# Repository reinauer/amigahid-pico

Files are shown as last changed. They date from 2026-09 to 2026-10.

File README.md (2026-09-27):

# amigahid-pico

please note: the interesting stuff goes into the [development](https://github.com/borb/amigahid-pico/tree/development) branch, so if main seems slow, check it out.

## introduction

amigahid-pico uses the rp2040 microcontroller (e.g. the raspberry pi pico) in a carrier board to attach usb input devices to a standard amiga without the need for a usb stack on the amiga itself.

it currently supports keyboards and mice and provides connection via the internal keyboard connector, the rj11/din socket on big-box amigas, and via the controller ports.

**this project is very much a work in progress.**

## **important note**

* current kicad files are for r5 pcb. on the `features` branch, select `BOARD_HIDPICO_REV5` to enable both controller ports: port 1 defaults to mouse and port 2 to USB joystick. REV4 firmware supports the same keyboard and first port, but leaves the second port unused. see [USB joystick mode](./doc/joystick.md).

* **always read the [errata](./doc/errata.md) section for the current pcb layout before deciding whether or not to build.**

rev 5 pcb

## documentation

* [installation](./doc/installation.md)
* [hardware](./doc/hardware.md)
* [errors in revisions (errata)](./doc/errata.md)

## history

this project is a rewrite of the [amigahid](https://github.com/borb/amigahid) project to the rp2040 microcontroller.

originally, after the retirement of the arduino adk board and shortening availability of the max3421e "usb host shield" for arduino boards, the need for a cheap, easy and continually available replacement was sought.

at first, the uhs mini via a level shifter seemed ideal, but significant issues were found convincing it to work with a variety of arduino boards.

the rp2040 made sense as a target because it is widely available, has sufficient physical connections and is powerful enough to meet multiple needs.

## what is the latency of this?

i have not measured the latency, but the keyboard signals are sent out the moment they are received on the usb bus. the potential latency is likely fractionally longer than the amiga mcu but bear in mind the rp2040 is significantly faster than the standard amiga keyboard controller.

## roadmap

please see the issues tab on the [github repository](https://github.com/borb/amigahid-pico) for the current list of planned features. the tl;dr is:

normal:
* i<sup>2</sup>c display for config/status
* controller emulation
    * keyboard-based controller emulation (use udlr for directions?)
* flash memory-based configuration
* possible amiga-side control panel (using bidirectional controller port signals)
* rotary control simulation (for controlling gotek drives)

crazy talk:
* non-amiga support
* non-hidbp support
* analogue/paddle emulation
* fix some tinyusb issues (hotplug, timing-related instability)

## license

on the fence at the moment, but the current license choice is Eclipse Public License 2.0 (EPL-2.0).

## third party licenses

* µgui: this code contains 'µgui' by achim döbler; the license for this can be read at in the [display readme](./src/display/README.md)

## whuh... who?

nine <[nine@aphlor.org](mailto:nine@aphlor.org)>

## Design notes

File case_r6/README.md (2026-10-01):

# AmigaHID Pico r6 case

YAPP enclosure for `../kicad_r6/amigahid-pico.kicad_pcb`. Outside dimensions are
**75.6 × 76.0 × 26.5 mm**. The base and lid are separate snap-fit parts. The lid uses **blind internal clip
recesses**, leaving 0.8 mm of continuous exterior wall. Matching base clips are
shortened with 0.15 mm clearance; print the updated base and lid together.

Run the build command below to generate the STL files and previews locally.
Generated `build/` files are intentionally excluded from Git.

## Print files

- [Base STL](build/base.stl), floor down.
- [Lid STL](build/lid.stl), exterior top face down; already oriented for printing.
- [Both parts](build/print.stl), separated on one build plate.
- [Editable OpenSCAD design](amigahid-pico-case.scad).
- [PCB and connector fit preview](build/fit.png), with simplified component envelopes.

PETG and a 0.2 mm layer height are reasonable starting settings, carried over from
the original case. Tune `ridgeSlack` and the port clearance after a first print.
This is a geometrically checked prototype, **not a physically test-fitted enclosure**.

## r6 changes

The original sibling repository was copied into this directory. Its original SCAD, README, assets and unused STEP helpers remain local-only
and are excluded from Git; the source license is retained. The r6 SCAD uses the actual
[YAPP_Box generator](https://github.com/mrWheel/YAPP_Box), vendored at commit
`f9400c419ef1dea7dc0b3607876989b4f3faa2b7` with its MIT license. Original case source:
`../amigahid-pico-case`, commit `84d0b1838114eac426ddd242eb8ad227578d349e`.

Coordinates are extracted from the current PCB, not copied from the old case.
Case X = KiCad X; case Y = 68 − KiCad Y, plus the wall and padding offsets.
The PCB origin lies at case (2.8, 5.2) mm, with the PCB top at Z=7.6 mm.

| Feature | Position and opening |
|---|---|
| J5/J6 DE9 | Two 32.0 × 13.7 mm openings on the +Y wall, at PCB X=17.54 and 51.54 mm; includes flange and screw access. |
| J7 A4000 mini-DIN | Ø15 mm opening on the +X wall, at PCB Y=20 mm, centre 6.55 mm above PCB. |
| J4 USB-A | 15.7 × 8.29 mm opening on the +X wall, at PCB Y=50.5 mm, centre 3.545 mm above PCB. |
| OLED | 32.22 × 17.5 mm lid window centred at PCB (51.0, 48.2) mm; matches the supplied 1.3-inch SH1106 drawing. |
| H5/H6 | Ø4.4 mm printed supports, 3 mm above the floor, at PCB (2.7,63) and (53.3,22.5) mm. |
| J9 external 5V | Optional 9 × 7 mm pigtail opening on the −Y wall, aligned with J9. Disabled by default. |
| J1 A500 cable | Optional 6 × 7 mm opening on the −X wall. Disabled by default for mini-DIN keyboard use. |

Connector openings use supplier mechanical drawings, including the offset between
DE9 footprint origins and their actual shell centres. Nominal shell dimensions:
DE9 30.8 mm wide × 12.5 mm high; JST USB-A 14.5 × 7.09 mm; DIN-603 14.2 mm
wide × 13.1 mm high. Supplier drawing URLs are recorded in `../kicad_r6/SOURCING.csv`.
The DIN opening allows plug mouldings up to about 14.4 mm diameter with clearance;
measure unusually bulky cable boots before printing.

The Pico antenna has the PCB's 14 × 9 mm notch beneath it and an extra 3 mm gap
at that end of the enclosure. There are no support posts in that region. Use a
nonmetallic case and nylon hardware; the base remains a continuous plastic floor.

## Assembly

1. Clear/tap the two 1.7 mm support pilots for M2 threads. Fix the PCB with
   **two M2 × 4 mm nylon screws** through H5/H6. Longer screws can bottom out.
2. Mount the OLED on **four 12 mm M3 nylon spacers** through H1–H4. The case
   supports the main board; it does not duplicate the OLED mounts in the lid.
3. The display stack assumes a 1.2 mm module PCB and 2.6 mm glass height above
   it. This leaves **0.6 mm** beneath the lid. Confirm the assembled stack before
   snapping shut; adjust `oled_standoff`, the stack dimensions and case height
   together if your module differs. The female J3 socket needs sufficient mating
   pin length to bridge the 12 mm spacing; use flying leads if necessary.
4. Set JP1 to the intended power source, connect the display and close the lid.
   Pico programming USB, BOOTSEL, JP1 and debug/experimental headers are accessed
   with the lid removed. No programming extension or push-button is included.

J9 is a PCB header, **not a panel power jack**. Its opening is for a low-profile
wired pigtail with strain relief added during assembly. A tall straight Dupont
plug under the OLED will not fit this stack. The wall is closed by default for Amiga keyboard power. Set
`external_power_opening=true` to enable the auxiliary-power cable opening.
The optional J1 cable opening similarly assumes flexible/low-profile wiring.

## Rebuild and checks

Open `amigahid-pico-case.scad` in OpenSCAD. `view` supports `print`, `base`, `lid`,
`assembled`, `fit` and `collision`. Change `oled`, `external_power_opening` or
`a500_cable_opening` to select apertures.

```sh
# From the repository root; requires KiCad's Python module.
/usr/bin/python3 case_r6/tools/extract_pcb.py
# Requires OpenSCAD on PATH, or OPENSCAD=/path/to/openscad.
python3 case_r6/tools/build.py
```

The generated, local-only `pcb-mechanics.json` records the source PCB hash and measured component positions.
`pcb-mechanics.scad` is a small committed geometry input so OpenSCAD can open
the design without a KiCad Python installation.
Extraction updates placement coordinates; board outline and connector type changes
still need mechanical review. Current cutout dimensions and pin-centre corrections
are for the selected r6 component part numbers.

The exported base and lid were checked for closed edges, positive volume, and
exactly one connected solid each. See `build/mesh-validation.json`. The modelled
PCB, connector, Pico and OLED envelopes have **zero volume of interference** with
the assembled enclosure. A 0.01 mm separation excludes intentional support/PCB
contact from that Boolean test. This checks nominal body clearance; it does not
validate every cable boot, solder joint, screw, printer tolerance or snap force.

The build also exports CSG for both parts. STEP conversion is not included or
validated in this revision.

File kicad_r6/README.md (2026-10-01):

# AmigaHID Pico r6 — prototype hardware

Open `amigahid-pico.kicad_pro` with KiCad 10. This directory was copied from
`../kicad`; the original r5 files and existing firmware edits are untouched.
The schematic and PCB in this directory are the r6 design, not fabrication-proven hardware.

## Implemented

- Pico **W** (RP2040, LCSC C7203003) fitted by default; also supports Pico **2 W**
  (RP2350) on the same footprint. Both modules provide Wi-Fi/Bluetooth. A bare RP2350 + RM2 design is
  deferred; it requires a separate MCU power/flash/clock/RF layout.
- Two **SN74CBTD3861DBQR** 10-channel bus switches replace all 17 BSS138 level
  shifters. Ten isolated 4 × 10 kΩ resistor arrays replace 34 individual
  pull-ups; unused resistor channels and switch channels are intentionally NC.
  These are the **CBTD** parts, powered from 5 V; CBTLV3861 is not a substitute.
- Two PCB-mounted **female DE9** connectors, numbered by actual DE9 pins rather
  than the old IDC/ribbon interleave. They connect to the Amiga's male ports.
- A **6-pin mini-DIN A4000 keyboard link**, for the user's straight-through
  PS/2-to-PS/2 cable and A4000-to-A3000 mini-DIN/DIN adapter. The signalling is
  Amiga keyboard protocol. This is not a PC PS/2 keyboard input.
- A four-pin female OLED socket, **3V3 / GND / SCL / SDA**, matching the supplied
  SH1106 module pin table. GPIO2 is SDA; GPIO3 is SCL.
- Four 3.2 mm carrier holes for M3 nylon standoffs on **30.50 × 28.60 mm** centres.
  The OLED outline is **35.50 × 33.70 mm**, from the supplied mechanical drawing.
- One USB-A host port. Full underside Pico W USB pads replace the old board
  crevice / half-via attachment. GPIO14/15 are exposed at J8 for a future PIO-USB
  experiment; the USB-A port currently uses the native USB controller.
- External 5 V input and a power-source selector, plus a 500 mA hold PTC on the
  USB host branch. An external powered USB hub provides multiple device ports.

Two additional case mounts, H5 at (2.70, 63.00) mm and H6 at (53.30, 22.50) mm,
use **2.2 mm holes for M2 nylon screws/standoffs**. Coordinates are measured from
the top-left board corner. Use hardware no wider than 4.4 mm at the PCB; M3
hardware crowds the Pico. H1–H4 remain the OLED mounts.

The carrier has a **14 × 9 mm antenna notch** from x=10 to 24 mm and y=59 to
68 mm, open to the bottom edge. This removes the carrier substrate beneath the
antenna, following the module footprint’s suggested board edge. Keep case metal
and mounting hardware out of that antenna space.

Board bounding outline: **70 × 68 mm**, two copper layers. The bounding rectangle is about 6.4% greater area
than the original outline's 61.772 × 72.443 mm bounding box. The level-shifting
section is smaller; the direct connectors and OLED mounting determine the
carrier size. Three onboard USB sockets and an onboard hub are not included.

## LCSC sourcing

`SOURCING.csv` records the selected manufacturer part numbers, live LCSC stock
counts, check timestamps, datasheet links, and footprint checks. The schematic
and PCB use only **LCSC Part #**, the field recognized by the Fabrication Toolkit
plugin. `production/bom.csv` uses the same **LCSC Part #** column. LCSC stock does not itself guarantee JLC assembly stock
or eligibility; check those when uploading the BOM.

All 32 electrical components have stocked LCSC selections. **U1 is Pico W,
C7203003**, selected after checking both official pinouts and SMT drawings.
Pico 2 W is an optional separately sourced alternative. Use firmware built for
`pico_w` with the fitted RP2040 module or `pico2_w` with the RP2350 alternative. The OLED, standoffs, cables, and JP1 shunt are separate assembly
accessories; mounting holes are not purchasable components.

- U1: C7203003, Raspberry Pi Pico W. See `review/sourcing/pico-compatibility.txt`
  for the underside-pad and shell-contact verification.
- U2/U3: C44508, TI SN74CBTD3861DBQR (SSOP-24, 0.635 mm pitch). This replaces
  the initially selected PWR/TSSOP package; the electrical pin assignments are
  unchanged. Use the updated PCB, not the previous TSSOP fabrication files.
- J7: C7428703, HOOYA DIN-603. The six signal holes, 13.9 mm shield spacing,
  central 3 × 1 mm shield slot, and signal numbering match the local footprint.
  Numbering was cross-checked against LCSC’s EasyEDA model as well as the drawing.
- J5/J6: C50380980, LCK-205A09FJ2A00B1A. Signal drills are 1.10 mm to meet the
  supplier’s 1.09 mm hole recommendation; 25 mm mounting-hole pitch is retained.
- J4: C7279912, JST UBA-4R-D14-4D(LF)(SN), matching the existing USB signal and
  shield-hole pattern. USB routing is retained.
- Connector 3D bodies are illustrative, not exact supplier mechanical models.

`review/sourcing/stock-snapshot.json` preserves the stock evidence. Stock counts
are a dated snapshot, not a reservation or an ongoing availability guarantee.

Assembly rotation corrections use `FT Rotation Offset` for Fabrication Toolkit:
U1 = 270°, C4 = 180°, J7 = 0°, and J1–J6/J8/J9/JP1 = 90°.
These offsets incorporate the assembly-preview corrections: U1 and C4 turned
180° from the preceding export, and J7 turned 90° clockwise. They affect only
exported placement rotation. Review pin 1, C4 polarity and connector openings
in the JLC preview after re-uploading the CPL.

## Power and assembly

**Default: regulated 5 V into J9, with a 2 mm pitch shunt on JP1 pins 2–3.**
J9 pin 1 is +5 V input; pin 2 is ground. Supply at least the measured Pico +
peripheral load; a current-limited 5 V bench supply is appropriate for bring-up.
The selector keeps the Amiga's keyboard +5 V separate in external-power mode.
Do not bridge both selector positions. Grounds remain common. Power the adapter and Amiga together; automatic I/O
isolation when either supply is off is not implemented and needs bench review.

JP1 pins 1–2 select power from the Amiga keyboard connector. Use that option
only after checking the actual machine's port budget; the complete 500 mA USB
branch must not be assumed available from a keyboard port. The PTC is overload
protection, not a precise 500 mA current regulator or a USB power-distribution
switch. Use a powered hub for multiple USB loads. DE9 pin 7 is deliberately NC
on both ports, so mouse-port supplies are not paralleled with keyboard power.

D1 feeds Pico VSYS through a Schottky diode, preventing the Pico's programming
USB supply from feeding the selected board rail. Disconnect host devices when
connecting a PC to the Pico's native USB connector: the two connectors share
D+/D-. Do not connect two USB hosts to those data lines.

The Pico module must be **surface mounted/reflowed**, including TP2 and TP3;
plugging it into ordinary 40-pin sockets does not connect the USB test pads.
The local Pico footprint retains the wireless antenna keepouts and omits only
two paste-only apertures which conflicted with its RF keepout. No connector,
OLED metalwork, ground fill or trace should extend into the antenna keepout.

The OLED pin row starts 11.28 mm to the right of the upper-left mounting-hole
centre and 1.54 mm below its PCB top edge, following the supplied drawing.
Use a matching four-pin female socket on the carrier. Approximately 11 mm
board-to-board spacing suits an 8.5 mm socket plus a 2.54 mm male-header body;
**dry-fit the actual supplied header and standoffs before assembly**. All four
OLED holes are part of the carrier; the module outline is on Dwgs.User.
Use nylon spacers to avoid shorting OLED tracks. The display sits above the
carrier components; confirm connector insertion clearance in the assembled stack.

## Connector pinouts

| Connector | Pins |
|---|---|
| J1 A500 | 1 KCLK, 2 KDAT, 3 /RESET, 4 Amiga +5 V, 5 NC, 6 GND, 7 NC, 8 NC |
| J2 UART/SWD | 1 GND, 2 GPIO0/TX, 3 GPIO1/RX, 4 SWDIO, 5 GND, 6 SWCLK |
| J3 OLED | 1 3V3, 2 GND, 3 SCL/GPIO3, 4 SDA/GPIO2 |
| J5/J6 DE9 | 1 Up, 2 Down, 3 Left, 4 Right, 5 button 3, 6 Fire, 7 NC, 8 GND, 9 button 2 |
| J7 A4000 | 1 KDAT, 2 NC, 3 GND, 4 Amiga +5 V, 5 KCLK, 6 NC; shell GND |
| J8 experiment | 1 GND, 2 GPIO14, 3 GPIO15, 4 3V3; no USB firmware or 5 V power at this header |
| J9 external supply | 1 regulated +5 V, 2 GND |
| JP1 2 mm selector | 1 Amiga +5 V, 2 board +5 V, 3 external +5 V; fit one shunt, default 2–3 |

Check the PS/2 cable for **pin-for-pin continuity**, especially 1, 3, 4 and 5.
The A3000 adapter must map A4000 mini-DIN data/clock/ground/supply to the matching
A3000 DIN signals. Do not infer numbering from the mating face or wire colours.
The mini-DIN does not carry A500 /RESET; J1 retains that signal.

## Firmware compatibility and remaining validation

Amiga GPIO assignments retain `BOARD_HIDPICO_REV5`, including the corrected
port-2 GPIO26/GPIO27 mapping. Firmware must drive the Amiga outputs LOW or
release them; the existing keyboard and controller drivers already do that.
The bus switches do not actively generate a 5 V HIGH; the 5 V pull-ups do.

A local Pico 2 W + Bluetooth build was attempted and failed at `src/settings.c:41`:
`Settings overlap Bluetooth pairing storage`. The installed picotool is also
2.2.0-a4 while this SDK requires 2.3.0; the compile check used
`PICO_NO_PICOTOOL=ON`, so it could not produce a UF2 even if compilation passed.
Resolve the flash partition configuration before treating RP2350 firmware as
ready. Logs are in `review/firmware-*.log`.

Pico 2 W requires a `pico2_w`/RP2350 firmware build with Bluetooth enabled;
Pico W requires `pico_w`/RP2040. A wireless footprint alone does not enable
Bluetooth in a firmware image. Existing firmware source is not changed here.

**The current display driver is SSD1306, not SH1106.** Despite the seller's
compatibility wording, SH1106 needs page-addressed writes, its DC/DC commands,
a typical two-column RAM offset and an I2C speed no higher than its specified
400 kHz. The current 1 MHz SSD1306 horizontal-addressing driver must be adapted
before the requested display can work. This hardware provides the correct
supply, signals and mounting, but does not claim SH1106 software support.

Before promoting this prototype to a manufacturing release:

1. Dry-fit the selected connectors, OLED/socket/spacers and cables. Supplier
   footprint checks and the exact selected parts are recorded in `SOURCING.csv`.
2. Check continuity, diode polarity, power selector isolation and all connector
   pinouts without an Amiga attached. Verify 5 V supply and 3.3 V rail sequencing.
3. Scope LOW/HIGH levels on both sides of both CBTD3861s under actual Amiga
   pull-ups and cable loads, including reset, simultaneous transitions, startup
   and shutdown. TI specifies the part's operating supply as 4.5–5.5 V.
4. Check the Pico pins for overshoot/back-powering in every supply state. The
   CBTD3861's transfer curve is not an absolute overvoltage clamp guarantee.
5. Test USB enumeration/hotplug with a keyboard, mouse and joystick through a
   powered hub. Check inrush, PTC heating, supply drop and USB waveform quality.
   The manually routed pair is matched to below 0.3 mm; this alone is not USB
   compliance or a verified 90-ohm impedance calculation for a chosen fab stackup.
6. Verify Bluetooth operation and RF range with the display and enclosure fitted.
7. Implement/test SH1106 firmware and verify the image reaches all display edges.

No remote release/tag is published and no fabrication order is placed.

## Files and reproducibility

- `amigahid-pico.kicad_pro`, `.kicad_sch`, `.kicad_pcb`: editable r6 project.
- `SOURCING.csv`: reviewed electrical component list with `LCSC Part #` fields.
  Run `python3 scripts/sync_sourcing.py` to generate `BOM.csv`; add OLED, a 2 mm shunt,
  four M3 nylon spacers and mating power/display connectors to the assembly order.
- `review/oled-*.png` and `review/sourcing/`: supplied mechanical drawings and
  sourcing evidence. Downloadable supplier PDFs are linked in `SOURCING.csv`.
  Exported schematics, board previews, validation reports, Gerbers and production
  files are generated locally and excluded from Git.
- `scripts/sync_sourcing.py`: reapplies reviewed `SOURCING.csv` metadata to the
  schematic, PCB and BOMs without changing the circuit or layout. It does not
  refresh live stock automatically.
- `scripts/validate_r6.py`: repeat the connectivity, mechanics, ERC and DRC checks
  using `/usr/bin/python3 scripts/validate_r6.py` from this directory.
- Local footprint/symbol libraries are project-relative. Only the four r6
  footprints and the required mini-DIN model are tracked. KiCad 10 supplies the
  remaining standard footprints and models. r5 references, caches and one-off
  placement/routing generators are excluded from Git.

## Sources

- [TI SN74CBTD3861 product page](https://www.ti.com/product/SN74CBTD3861)
  and [datasheet](https://www.ti.com/lit/ds/symlink/sn74cbtd3861.pdf).
- [Raspberry Pi Pico 2 W datasheet](https://datasheets.raspberrypi.com/picow/pico-2-w-datasheet.pdf).
- [Raspberry Pi RM2 documentation](https://www.raspberrypi.com/documentation/microcontrollers/radio-modules.html).
- [Commodore A4000 schematic, CN175](https://www.amigawiki.org/dnl/schematics/A4000_Rb.pdf).
- [Sino Wealth SH1106 datasheet](https://www.crystalfontz.com/controllers/SinoWealth/SH1106/468/).
- OLED dimensional drawing and pin table supplied by the user in this session;
  saved under `review/` with the original dimensions visible.

Original project author: nine <nine@aphlor.org>. See the repository README for
the project's Eclipse Public License 2.0 licensing statement.

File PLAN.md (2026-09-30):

# Implementation status: features branch (2026-09-29)

Based on `bluetooth` at `b437643`. The existing Bluetooth PR is unchanged.

Implemented in the first runtime-configuration milestone:

- Versioned settings with CRC validation, defaults, and two alternating flash
  records. Settings storage is separate from Bluetooth pairing data.
- OLED settings menu entered by holding F12 for one second; arrow navigation,
  save, cancel, and factory defaults. Input is captured while the menu is open.
- Menu key/entry policy, Right GUI behavior, wheel enable/direction,
  quadrature timing presets, display diagnostics/off, and optional watchdog.
- Fixed boot recovery: hold F12+Esc for two seconds during the first ten seconds
  of input servicing. Defaults are applied in RAM; save explicitly to keep them.
- The watchdog feeds only after the main-loop services return; it is off by
  default. USB-only builds also initialize core1's flash lockout support.

Hardware check on Pico W/REV5 (initially using the REV4 firmware): the menu works,
and a saved 5-second watchdog setting survives power loss. Recovery and an actual watchdog-triggered restart
still need hardware validation.

Usage and validation notes: [doc/runtime-configuration.md](doc/runtime-configuration.md).

Implemented in the digital-joystick milestone:

- USB HID gamepad/joystick hat switches, discrete D-pad inputs and absolute X/Y
  fields, with Button 1 as fire. Reports are decoded from their descriptors,
  including report IDs. X/Y uses a central deadzone and digital output.
- A dedicated REV5 build defaults to mouse on controller port 1 and USB joystick
  on port 2 simultaneously. Port 1 can still select joystick; port 2 has an Off
  option. REV2/REV4 retain port 1 only. Core1 owns output pins; menu entry, mode
  changes and disconnects release controls. Opposing directions cancel.
- Settings schema 3 migrates schema 1 and 2, preserving existing settings and
  enabling the new port 2 option by default on REV5. A saved port 1 joystick
  selection is retained; change it to Mouse for the two-port arrangement.

Usage and supported formats: [doc/joystick.md](doc/joystick.md).

Competition Pro Extra (`0079:181c`) input checked on Linux: its digital stick uses
X/Y values 0/128/255, with the advertised hat unused. Native decoding checks pass
using the actual descriptor and captured axis values. All four buttons produced
events. Initial hardware testing detected the controller, but Amiga Test Kit showed no
activity on either port, including port 1 through the working mouse cable.
HID diagnostics now expose USB report count/length, decoding, routed controls
and waiting for neutral. On direct USB connection, the stick showed zero received
reports and an advertised 49-byte layout instead of Linux's 9-byte layout.
A PS3 startup trial now matches `054c:0268` plus the 49-byte report ID 1 layout
before enabling input, and maps PS3 face buttons to fire. The user confirmed that
`0.3.0-dev-12-g4da9d14` works on REV5 by playing Great Giana Sisters. The controller's
USB identity was not read back directly; the successful initialization supports
the PS3-mode explanation. Detailed unplug/menu/diagonal checks remain outstanding.

Implemented in the Bluetooth LE gamepad milestone:

- Active LE scanning includes scan responses. Devices without keyboard/mouse boot
  reports use BTstack's HIDS host to discover report maps and subscribe to input.
- Standard HID gamepad reports feed the existing digital joystick path. The Stadia
  Bluetooth descriptor has native coverage for D-pad, left stick and A/fire.
- The Bluetooth queue preserves the latest gamepad state on overflow and releases
  controls on disconnect. OLED status identifies an accepted LE gamepad, with
  report/decoding/output diagnostics when no USB joystick is connected.
- Controller menus now say Joystick because the same mode accepts USB and LE
  input. Existing saved settings and the REV5 mouse/joystick defaults are preserved.
- Stadia is the first hardware target. Keyboard-as-joystick is deferred at the user's
  request; Bluetooth gamepads take priority.

Hardware check on Pico W/REV5 with `0.3.0-dev-13-gde9ae63`: Stadia connected,
the OLED reached `bt c0 le:ready j1`, and D-pad directions and A/fire worked on
Amiga port 2 in Amiga Test Kit. Left-stick thresholds, disconnect release,
reconnection and extended play still need hardware validation. The USB-only
device counters remain unchanged; Bluetooth status is shown on the second line.

Implemented in the PS4 Bluetooth trial:

- Classic inquiry automatically finds joystick/gamepad devices and opens HID
  connections. Discovery pauses once a Classic gamepad is accepted and resumes
  on disconnect; incoming keyboard/mouse connections remain supported.
- Standard Classic gamepads use the existing descriptor decoder. DualShock 4
  Bluetooth uses a descriptor-matched decoder for basic and extended reports:
  D-pad/left stick supply directions and Cross supplies fire.
- Extended reports are requested for touchpad input. A finger drives relative
  mouse movement on port 1; pressing the pad supplies left-click. Contact tracking
  prevents jumps on lift/re-touch. Extended reports are length/CRC checked.
- Bluetooth diagnostics include Classic gamepads. No settings schema changes.
- Temporary native checks cover discovery, pairing failures, incoming reconnect,
  published descriptors, joystick/touchpad reports and disconnect release.
  The user confirmed the initial trial works on REV5, including touchpad
  left-click. Reconnect and long-running stability still need hardware checks.

Implemented in the additional-buttons trial:

- Joystick buttons 1/2/3 drive Amiga pins 6/9/5 on each enabled joystick port.
  PS4 uses Cross/Circle/Square, Stadia uses A/B/X. Generic HID uses Buttons
  1/2/3, falling back to Button 4 for the third fire if Button 3 is absent.
  The Competition Pro PS3-mode four-buttons-as-fire mapping is preserved.
- PS4 L1/touchpad press supply left-click, R1 right-click, and either L2 or R2
  supplies middle-click on the mouse port. USB/Bluetooth mouse buttons are
  combined so one device cannot release a button held on another.
- Temporary checks cover button combinations, source aggregation, menu capture,
  disconnect release, and all seven digital output lines on both REV5 ports.
  No settings schema changes or new checked-in tests.

Hardware check on Pico W/REV5 with `features-ps4-stadia-buttons-20260928`
(`0.3.0-dev-14-g7489e0d*`): the user confirmed that PS4 and Stadia joystick
buttons 1/2/3 and the PS4 mouse button mappings all work as expected.
Reconnect and long-running stability still need hardware validation.

Implemented in the configuration and CD32 milestone (hardware test pending):

- Bluetooth radio On/Off, automatic or bonded-only pairing policy, a timed pairing
  action and confirmed removal of Classic/LE bonds. Stored LE identities support
  private-address resolution. Radio shutdown discards stale input and releases controls.
- Gamepad D-pad/stick selection, three deadzones, seven configurable button sources,
  and PS4 touchpad/shoulder mouse controls. Controller-specific defaults are retained.
- Keyboard Help/Delete choices, ISO-key selection, letter-layout presets and eight
  learned-source custom remaps. Translated keys are aggregated across devices so
  aliases and shared modifiers stay held until every source releases them.
- CD32 pad mode on supported ports: PIO provides the seven-button shift register,
  identification bits and fire/clock handover. REV5 can retain mouse on port 1 and
  CD32 on port 2. Explicit CD32 mode preserves ordinary joystick as the default.
- Settings schema 7 reads schemas 1–6 and preserves saved choices. Live settings
  are published atomically to Bluetooth callbacks. No CAD changes or new checked-in tests.
- Temporary checks pass settings migration/interrupted writes, menu actions, key
  aliases and reset chord order, seven-button decoding, Bluetooth power/pairing/
  forget transitions, parser mutation cases, GPIO routing and assembled CD32 PIO
  behavior. CD32 recognition/electrical timing and the new menu settings need the
  user's combined hardware test; software simulation is not hardware validation.

Still to implement or validate:

- Test the four new feature groups on Pico W/REV5, including saved settings,
  controller disconnect/reconnect, held-control release and extended use.
- Validate boot recovery and an actual watchdog-triggered restart.
- Measure input latency and validate faster mouse timing presets on hardware.
- Earlier HID rearming and GPIO timing instrumentation.
- Keyboard PIO; consider mouse PIO only after measurement.
- Keyboard-as-joystick remains deferred at the user's request.
- Additional controller formats and optional automatic port mode selection.
- Full national keyboard layouts beyond the letter presets/custom remaps, and
  arbitrary remapping beyond the eight custom slots.
- The optional Amiga preference tool.

The sections below retain the design and acceptance criteria for these phases.

# PIO Offload Plan

## Goal

Reduce end-to-end input latency without regressing keyboard or mouse
reliability on the Amiga.

## Current State

- USB host processing runs on `core0`.
- Keyboard state updates still happen on `core0`, but the blocking
  Amiga wire transmission is now queued out of the HID callback path.
- The current keyboard sender still bit-bangs the Amiga serial protocol,
  but that work is now serviced from the normal event loop instead of
  stalling USB report handling directly.
- Mouse quadrature output already runs on `core1`.
- The current mouse path uses a 64-bit deadline with a default 300 us step
  interval. The features branch makes that interval configurable; faster
  presets still need hardware validation.

## Priority

1. Tune or redesign mouse pacing.
2. Measure the result.
3. Shorten the HID hot path further if needed.
4. Only implement mouse PIO if measurements still justify it.

## Phase 1: Measure Baseline

- Add simple timing instrumentation for:
  - USB report received
  - keyboard send start and end
  - first mouse quadrature edge after a report
- Compare:
  - direct USB mouse and keyboard
  - the same devices through the KVM
- Record:
  - typical latency
  - worst-case latency
  - burst behavior

## Phase 2: Decouple Keyboard Sending

Completed.

- Stop sending Amiga keyboard codes directly from the HID callback path.
- Add a small queue for translated Amiga key events.
- Keep key translation, modifier tracking and caps lock handling on
  `core0`.
- Move the actual wire-level transmission out of the synchronous USB
  path.

## Phase 3: Implement Keyboard PIO

- Replace the current blocking keyboard bit-bang transmitter with a
  PIO-backed sender.
- Feed pre-encoded key events into a PIO state machine from software.
- Preserve current behavior for:
  - key up and key down encoding
  - caps lock special handling
  - Ctrl-Amiga-Amiga reset behavior
- Keep a software fallback until the PIO path is validated on hardware.

## Phase 4: Reevaluate Mouse Latency

- Re-test after the keyboard work lands.
- Measure whether the remaining mouse lag is dominated by:
  - KVM polling or buffering
  - the `motion_divider`
  - the fixed `300 us` quadrature pacing
- If needed, make the quadrature step delay configurable and test lower
  values before attempting a larger rewrite.

## Phase 5: Mouse PIO Only If Needed

- Consider mouse PIO only if measurements show that the current
  `core1` quadrature loop is still a significant source of latency or
  jitter.
- A mouse PIO implementation should focus on:
  - precise quadrature timing
  - higher sustained output rate
  - lower burst drain time
- Do not treat mouse PIO as the first optimization target, since the
  current mouse path already avoids blocking USB handling on `core0`.

## Acceptance Criteria

- Keyboard transmission no longer blocks USB event handling for several
  milliseconds per keycode.
- No regressions in key mapping, caps lock behavior or reset chord
  handling.
- Mouse movement remains correct on both axes with no button regressions.
- Measured latency improves in a way that is noticeable on hardware, not
  just in code structure.

## Status Against Earlier Latency Findings

Already addressed in the current tree:

- The old cross-core mouse handoff race has been replaced with a queue.
- Core1 now re-merges newly queued motion between quadrature steps.
- Per-report mouse debug is disabled by default and only enabled when
  `DEBUG_MOUSE` is set.
- Blocking Amiga keyboard transmission has been moved off the USB HID
  callback path into a queue serviced from `amiga_service()`.

Still open:

- Hardware validation of the configurable quadrature timing presets
- HID callback still rearms after handling the report
- No built-in latency instrumentation

## Remaining Work With Estimated Latency Impact

### 1. Make Quadrature Step Timing Configurable

- Implemented on features: select a 300, 200, 150, or 100 us step interval.
  The 300 us default is unchanged; faster presets need hardware testing.
- Test lower values such as `200 us`, `150 us` and `100 us`.
- Choose the lowest value that still tracks reliably on real hardware.

Estimated latency reduction:

- tiny movements: roughly `0-1 ms`
- medium bursts: roughly `3-8 ms`
- `50`-step bursts: roughly `7.5-10 ms`
- very large bursts: up to roughly `20 ms`

This is the highest-value remaining item for pure mouse feel.

### 2. Rearm HID Reports Earlier In The Hot Path

- Copy the essential report data quickly.
- Re-request the next HID report before doing lower-priority work where
  practical.

Estimated latency reduction:

- typical cases: roughly `0-0.2 ms`
- worst-case jitter under load: roughly `0.5-1 ms`

This is now a cleanup improvement rather than the main latency win.

### 3. Add GPIO Timing Instrumentation

- Toggle one GPIO on USB report receipt.
- Toggle another on first emitted quadrature edge.
- Compare direct USB devices against the same devices through the KVM.

Estimated latency reduction:

- direct reduction: `0 ms`

This does not improve latency by itself, but it is the fastest way to
separate KVM delay from firmware delay and validate whether the
remaining work is worth doing.

### 4. Implement Keyboard PIO As A Follow-Up

- Replace the queued bit-bang sender with a PIO-backed transmit path.
- Keep the queue-based architecture, but hand the actual waveform
  generation to a state machine.

Estimated latency reduction:

- USB callback blocking: roughly `0 ms` additional reduction, since the
  main callback decoupling is already done
- keyboard queue drain time under heavy typing: potentially `1-5 ms`
- jitter during mixed input under sustained key bursts: modest but real

This is still worth doing, but it is no longer the first latency item to
attack.

# Joystick Emulation Plan

## Goal

Add joystick and joypad emulation on top of the existing HID input
paths, starting with the simplest and most compatible target.

## Recommended Order

1. HID joystick and gamepad to Atari-style digital joystick
2. Keyboard-to-joystick as an explicit special mode
3. CD32 pad emulation

## Why This Order

- Plain digital joystick is the simplest controller-port target and
  reuses the same physical Amiga port lines already driven for mouse
  emulation.
- Keyboard-to-joystick is useful, but it should be an explicit mode so
  normal typing is not affected.
- CD32 pad support is more complex because the extra buttons are not
  just plain digital joystick inputs and need separate handling.

## Phase 1: HID Joystick to Digital Joystick

USB, LE and Classic HID hat/D-pad, absolute X/Y and multi-button support is
implemented on `features`. Competition Pro, Stadia and PS4 input work on REV5;
complete lifecycle testing and validation of the new configurable thresholds remain outstanding.
See [doc/joystick.md](doc/joystick.md).

- Add a controller backend that drives one Amiga controller port as:
  - up
  - down
  - left
  - right
  - fire
- Parse USB HID joystick and gamepad reports into that state.
- Support D-pad inputs first.
- Add analog stick support after that with deadzones and axis-to-digital
  thresholding.
- Keep the first implementation to one emulated joystick port unless
  the board pin mapping is expanded.

## Phase 2: Keyboard as Joystick Mode

- Add a dedicated mode that maps selected keys to joystick directions
  and fire buttons.
- Start with a sensible default mapping such as:
  - WASD for directions
  - space and ctrl for fire
- Make the feature opt-in so those keys still work normally in standard
  keyboard mode.
- Implement it as a virtual controller source, not as special cases in
  the normal keyboard path.

## Phase 3: CD32 Pad Emulation

Implemented with PIO on `features`; first hardware validation is pending.

- Add a separate backend for CD32-compatible controller output.
- Reuse the basic digital directions from the earlier joystick backend.
- Implement the extra CD32 button handling after the plain joystick path
  is stable.
- Keep this work isolated from the first joystick milestone so the
  simpler one-button case can ship earlier.

## Design Notes

- Reuse the shared input bridge pattern where it helps, so USB and
  Bluetooth controllers can feed the same Amiga-side output path.
- Keep joystick output independent from mouse output, even though they
  share the same Amiga controller connector pins.
- Provide a simple way to select the active emulation mode for a port:
  - mouse
  - joystick
  - keyboard as joystick
  - later, CD32 pad

## Acceptance Criteria

- A standard USB or Bluetooth gamepad can control Amiga software that
  expects a plain digital joystick.
- Keyboard-as-joystick mode works without leaking those keys into normal
  keyboard input when the mode is enabled.
- The initial joystick implementation is stable on hardware and does not
  regress existing mouse emulation.
- CD32 support remains a separate follow-up until the basic joystick
  path is proven.

# Runtime Configuration Plan

## Goal

Move user-facing configuration out of build-time defines where practical
so hardware can be assembled, fitted and adjusted without rebuilding
firmware for small behavioral changes.

## Motivation

- Some choices are annoying to validate only at build time, such as key
  remaps and mode selection.
- A misconfigured modifier or special key can block important machine
  functions such as the Amiga reset chord.
- The board already has an OLED on supported revisions, which makes a
  simple local configuration UI realistic.
- Settings should persist across power cycles and allow recovery to
  defaults.

## Scope

- Keep hardware-specific pin mapping as a build-time concern unless a
  safe runtime board-detection mechanism is added later.
- Move behavioral settings to runtime where possible, such as:
  - HID to Amiga key remaps
  - menu key versus right GUI behavior
  - mouse wheel mode and direction
  - mouse quadrature timing preset
  - port mode selection
  - joystick mode options
  - debug display preferences
  - Bluetooth behavior that does not affect low-level bring-up
- Keep hardware-specific and low-level electrical choices as build-time
  settings:
  - board type
  - GPIO pin mapping
  - PIO allocation details
  - port electrical assumptions

## Phase 1: Define Settings Model

- Add a single settings structure with:
  - version
  - checksum or CRC
  - defaults marker
  - behavioral options only
- Define factory defaults in one place.
- Keep the initial schema small and focused on the highest-value v1
  settings:
  - menu entry key, defaulting to F12
  - menu entry behavior, such as long-press or boot-only
  - right GUI behavior:
    - pass through as Right-Amiga
    - use as menu key
    - disable
  - mouse wheel mode:
    - off
    - TankMouse/Cocolino
  - mouse wheel direction:
    - normal
    - vertical reverse
  - mouse quadrature timing preset
  - debug display mode:
    - normal status
    - HID debug
    - mouse debug
    - off
  - watchdog enable and timeout preset
- Defer broader settings until the core storage and menu path are
  proven:
  - full custom key remapping
  - keyboard layout presets
  - joystick and gamepad mapping
  - Bluetooth pairing policy
  - CD32 pad mode

## Phase 2: Flash Persistence

- Reserve a flash region for configuration storage.
- Add load, validate and save helpers.
- On boot:
  - load settings from flash
  - validate version and checksum
  - fall back to defaults if invalid
- Add a reset-to-defaults path that can be triggered even if saved
  settings are broken.

## Phase 3: Runtime Menu

- Add a display-backed configuration menu for boards with `HAS_SCREEN`.
- Keep the first UI simple and robust:
  - current value
  - next and previous item
  - save
  - reset to defaults
- Avoid requiring a host computer or serial console for normal setup.
- If no display is present, continue to boot with saved settings and
  defer UI work for headless configuration until later.

## Phase 4: Input and Navigation

- Define how to enter the menu safely at boot or runtime.
- Use a key that exists on typical PC keyboards but is not forwarded as
  a normal Amiga key; F12 is the preferred default.
- Support long-press entry at runtime to avoid accidental activation.
- Support a boot-time entry path and a reset-to-defaults gesture so a
  broken saved configuration can be recovered.
- Choose a navigation method that does not require special hardware,
  such as:
  - keyboard keys
  - a connected mouse or controller
  - a held boot gesture
- Ensure the menu can always be exited without corrupting saved state.

## Phase 5: First Runtime-Configurable Features

- Start with settings that solve real deployment pain:
  - menu entry key and entry behavior
  - right-Amiga mapping choice
  - mouse wheel mode and vertical direction
  - mouse quadrature timing preset
  - optional debug screen toggles
  - watchdog enable and timeout choice
- Keep each setting independent and easy to reset.

## Phase 5a: Follow-Up Runtime-Configurable Features

Port/CD32 selection, gamepad settings, Help/Delete choices, letter presets, custom
remaps and Bluetooth controls are implemented. Automatic port detection and
keyboard-as-joystick remain future work. The original design follows.

- Add these after the settings model, flash storage and menu UI are
  stable:
  - controller port mode selection:
    - mouse
    - digital joystick
    - auto, if detection is reliable enough
  - keyboard-as-joystick enable and keymap preset
  - gamepad mapping:
    - D-pad versus analog stick
    - fire button mapping
    - analog thresholds and deadzones
  - Help/Delete mapping choices for different PC keyboard layouts
  - keyboard layout preset
  - Bluetooth enable, pairing mode and forget-paired-devices action
  - CD32 pad mode, once CD32 output is implemented
- Avoid starting with a full arbitrary key remapper; it is useful, but
  it will make the first settings schema and UI much larger.

## Phase 6: Migration and Safety

- Add schema versioning so future firmware can migrate old settings.
- Protect against partial writes and invalid flash contents.
- Make the default path conservative so a bad config does not leave the
  device unusable.
- Document a physical or boot-time recovery path for resetting config.

## Phase 7: Watchdog Support

- Add RP2040 watchdog support around the normal main event loop.
- Feed the watchdog only when the system is making forward progress in
  the expected loop.
- Choose a timeout that tolerates normal long operations but still
  recovers from real hangs.
- Record the last reboot reason where practical so watchdog resets are
  distinguishable from power-on resets.
- Make watchdog support configurable at runtime and default it to the
  behavior that proves least surprising in practice.
- Allow the watchdog to be disabled from saved settings because forced
  reboot behavior may be irritating during development or debugging.

## Watchdog Design Notes

- Do not feed the watchdog from many unrelated places, or it will stop
  detecting the actual main-loop stalls we care about.
- Keep the watchdog decision in the runtime settings model rather than a
  separate ad-hoc switch.
- Ensure there is still a recovery path if a saved watchdog setting is
  undesirable, such as booting into the menu or resetting config to
  defaults.

## Acceptance Criteria

- A user can change common behavioral settings without rebuilding the
  firmware.
- Settings persist across power cycles.
- Invalid or missing settings cleanly fall back to defaults.
- A broken configuration can be reset without external tools.
- The runtime menu does not interfere with normal input handling when it
  is not active.
- Watchdog behavior can be enabled or disabled without rebuilding the
  firmware.

## Experimental Follow-Up: Amiga Preference Panel

- Consider a native Amiga-side preference tool as a later extension of
  the runtime configuration work.
- This would use the controller-port button lines as a low-speed
  bidirectional signaling path only while an explicit configuration
  session is active.
- Do not treat this as the primary configuration path. The OLED menu and
  local runtime settings remain the first-class solution.

### Preconditions

- A reliable local runtime configuration system must exist first.
- The communication mode must not interfere with normal mouse, joystick
  or future CD32 behavior.
- There must be a clear way to enter and leave communication mode.

### Protocol Requirements

- Add an attention or wake-up signal that is unlikely to be triggered by
  normal input activity.
- Use a small half-duplex protocol with:
  - framing
  - versioning
  - checksum or CRC
  - timeout and retry behavior
- Abort cleanly back to normal port behavior if negotiation fails.

### Safety Requirements

- Keep the feature disabled unless explicitly invoked.
- Ensure failed communication cannot leave the controller port stuck in a
  non-input mode.
- Preserve a fully local recovery path through the OLED menu or reset to
  defaults even if the Amiga-side tool is unavailable.

### Scope

- Read current settings
- Change selected runtime settings
- Save settings to flash
- Reset settings to defaults

### Non-Goals for the First Version

- Replacing the OLED menu
- Streaming normal input events over the config channel
- Combining config traffic with normal mouse or joystick emulation at
  the same time

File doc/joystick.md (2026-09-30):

# Joystick mode

The `features` firmware supports a three-button digital joystick and CD32 pad emulation. On REV5 boards,
port 1 defaults to mouse and port 2 to joystick, working simultaneously. Use a
`BOARD_HIDPICO_REV5` build for this arrangement. Keyboard input continues normally,
including access to the settings menu.

## Setup

1. Connect the board's first controller cable to Amiga port 1 and its second cable
   to Amiga port 2. The actual Amiga sockets determine which port software sees.
2. Connect a supported USB HID gamepad or joystick. The OLED's USB `j` count
   increases when a supported controller descriptor is found. For Bluetooth,
   use the [Stadia](#bluetooth-le-gamepad-trial) or [PS4](#ps4-bluetooth-trial)
   instructions below.
3. The REV5 defaults are **Controller port 1: Mouse** and
   **Controller port 2: Joystick**. To check or change them, hold F12 for one
   second, release it, and use the settings menu. Select **Save and exit** after edits.
4. Centre the stick/D-pad and release all buttons before testing directions and fire.

The stick/D-pad provides up, down, left, right and diagonals. Generic HID Buttons
1, 2 and 3 supply the three fire buttons; Button 4 is used for the third fire when
Button 3 is absent from the descriptor (as on Stadia). PS3 USB mode retains its
four-face-buttons-as-fire-1 mapping for the Competition Pro. The saved
mode survives power loss. Port 2 can be turned Off independently. If an earlier
trial saved port 1 as USB joystick, select Mouse there to restore mouse input.
The menu now calls this mode Joystick; existing saved choices keep their meaning.

REV2 and REV4 builds support only controller port 1, where Mouse and Joystick
remain alternative modes. REV4's second port has a hardware wiring error; see
the [errata](errata.md#board-revision-4). Do not use a REV5 build on an unmodified
REV4 board. The REV5 port-2 mapping is Up GPIO27, Down GPIO26, Left GPIO22,
Right GPIO21 and buttons 1/2/3 on GPIO20/19/18 respectively.

The Amiga can read buttons 1/2/3 on DE-9 pins 6/9/5. Amiga Test Kit displays
these separately in Joystick mode; its `2` and `3` labels are always drawn and
do not indicate that a particular controller was detected. Games must explicitly
read the extra buttons to use them. See the
[hardware pinout](https://www.theflatnet.de/pub/cbm/amiga/AmigaDevDocs/hard_e.html)
and [Amiga Test Kit's button reader](https://github.com/keirf/amiga-stuff/blob/master/testkit/joymouse.c).

All connected USB and Bluetooth gamepads currently feed one combined joystick state. If both REV5
ports are configured as joystick, both output that state; independent player
assignment and mouse on port 2 are not implemented.

## Supported input

- USB HID Game Pad or Joystick application collections.
- Four- or eight-way hat switches, or separate HID D-pad direction usages.
- Absolute X/Y fields mapped to digital directions. These include digital sticks
  such as the Competition Pro, which reports its switches as X/Y values.
- Three fire buttons from HID Button usages 1, 2 and 3 (or 4 if 3 is absent).
- Report IDs, including directions and fire in separate reports.
- PS3 USB controllers identifying as `054c:0268` with input report ID 1 and a
  49-byte report. An asynchronous feature-report command enables input; the
  D-pad and descriptor-defined X/Y axes supply directions, and the four face
  buttons supply fire. This includes the PS3 mode used by some Competition Pro
  controllers. The device identity and report layout must both match before
sending the startup command. Other HID devices keep generic handling.

X/Y values in the central half of the descriptor's logical range are neutral;
values in the outer quarters select a direction. Low X means left, low Y means
up. Relative axes are ignored. Hats and X/Y can both supply directions; opposing
directions cancel. Deadzone and button mapping are configurable in the OLED menu; see below.

Bluetooth LE and Classic gamepads with standard HID reports use the generic
decoder. DualShock 4 Bluetooth has a separate decoder for its simple and extended
reports, with Cross/Circle/Square as fire buttons and touchpad mouse input. Proprietary/XInput reports,
and keyboard-as-joystick are not implemented yet. Controllers other
than the tested PS4, Stadia and Competition Pro still need hardware validation.
The generic parser supports up to four input report IDs, thirty-two mapped fields
and 64-byte reports. Unsupported controller layouts are not treated as mice.

Opening the menu releases all joystick controls. After closing it or switching
modes, centre the gamepad and release buttons before input resumes. Unplugging a
controller releases its controls; other connected controllers retain their
state. Opposing directions cancel when multiple controllers are active.

## Bluetooth LE gamepad trial

The first target is a Stadia controller already converted to Bluetooth mode.
Use the Pico W USB + Bluetooth build for your board revision.

1. Keep **Controller port 1: Mouse** and **Controller port 2: Joystick** on REV5.
2. Turn on the controller and put it in pairing mode: hold **Stadia + Y** for
   two seconds until its light pulses orange. See
   [Google's pairing instructions](https://support.google.com/stadia/answer/13067284?hl=en).
3. The Pico scans automatically. OLED status progresses through `le:scan`,
   `le:conn`, `le:pair` and service discovery. `le:pad` is gamepad report discovery;
   **`bt c0 le:ready j1`** means the LE gamepad report map has been accepted.
   The `c` number counts Classic connections, so `c0` is normal for Stadia.
4. Use the **D-pad or left stick** for directions and **A/B/X** for joystick
   buttons **1/2/3**. Centre the stick and release all controls after leaving
   the settings menu. Y remains unmapped.
5. Test directions, diagonals and fire in Amiga Test Kit, then turn off and
   reconnect the controller. Disconnecting must release held directions and fire.

Only one LE device can be connected at a time in this implementation. USB and
Classic Bluetooth keyboards/mice can remain connected. Rumble, right-stick
mapping and separate player assignments are not implemented.
Stadia pairing and D-pad/A-button input on Amiga port 2 are confirmed on REV5
with `0.3.0-dev-13-gde9ae63`. Left-stick thresholds, disconnect release,
reconnection and extended play still need hardware validation. All three A/B/X
button mappings are confirmed on REV5 with `features-ps4-stadia-buttons-20260928`.

The new path reads HID Report Maps and Report References and subscribes to input
notifications using BTstack's HIDS host. Existing LE boot keyboards/mice retain
their boot-report path. Standard gamepad reports use the same bounded decoder as
USB; gamepad axes are never passed to the mouse decoder on this LE path.

## PS4 Bluetooth trial

Use the Pico W USB + Bluetooth REV5 build. Keep **Controller port 1: Mouse**
and **Controller port 2: Joystick**.

1. Disconnect USB from the DualShock 4. If it is on, hold PS until it turns off.
2. Hold **SHARE + PS** until the light bar flashes. See
   [Sony's pairing instructions](https://www.playstation.com/en-us/support/hardware/ps4-pair-dualshock-4-wireless-with-pc-or-mac/).
3. The Pico searches for Classic Bluetooth gamepads automatically in short rounds,
   with five-second pauses. `c0:scan` means Classic discovery; `c0:conn` means a
   connection attempt. A successful PS4 connection normally shows
   **`bt c1 le:scan j1`**. `le:scan` is the independent LE scanner, so it is normal
   for it to remain visible while using a PS4 controller.
4. Use the D-pad or left stick for directions, with **Cross/Circle/Square** as
   joystick buttons **1/2/3** on port 2. Triangle remains unmapped.
5. Move one finger on the touchpad to move the mouse on port 1. Mouse buttons:
   **L1 or touchpad press = left**, **R1 = right**, **L2 or R2 = middle**.
   Either trigger works alone, and simultaneous buttons are supported. Lifting
   and replacing a finger starts a new movement without jumping the pointer.
6. After pairing, try switching the controller off and reconnecting with PS.
   Held directions, fire and mouse buttons must release on disconnect.

The firmware identifies the standard DualShock 4 Bluetooth report descriptor
before requesting feature report 2 to enable extended input. It handles
10-byte report 1 and 78-byte report 17, including the latter's CRC. With HID
diagnostics enabled and no USB joystick attached, `l78/78 d+` confirms that
extended packets are arriving and decoding; `l10/10 d+` means basic joystick
input without touch movement. The first USB device-count line excludes Bluetooth.

Discovery stops once a Classic gamepad is accepted and resumes after it disconnects.
One Classic gamepad is discovered automatically; the two Classic HID connection
slots can also serve a keyboard or mouse. A Stadia/other LE device can coexist.
All gamepads still share one joystick output state. Touch gestures,
rumble, light-bar control and motion sensors are outside this trial. Controller
clones with different descriptors are not identified as DualShock 4.

The user confirmed that the first PS4 trial works on REV5, including touchpad
left-click. All three joystick buttons and the shoulder/trigger mouse mappings
are also confirmed with `features-ps4-stadia-buttons-20260928`
(`0.3.0-dev-14-g7489e0d*`). Reconnect and extended use still need hardware
validation. Temporary native checks cover published DS4/DS5 descriptors,
discovery and connection callbacks, extended-mode setup, input decoding, CRC and
length validation, contact tracking, held-control release and queue overflow.
They also cover all face/shoulder/trigger button combinations, GPIO output for
all three joystick buttons, and independent mouse-button holds across USB and
Bluetooth sources: releasing one device cannot release a button held on another.
Wire-format references are
[hid-tools' Sony controller definitions](https://github.com/bentiss/hid-tools/blob/master/hidtools/device/sony_gamepad.py)
and [Bluepad32's DS4 driver](https://github.com/ricardoquesada/bluepad32/blob/main/src/components/bluepad32/parser/uni_hid_parser_ds4.c).

## Diagnosing missing input

Hold F12, select **Display: HID diagnostics**, then **Save and exit**.
With a supported controller connected, the two diagnostic rows show, for example:

```text
j002a l09/09 d+ r+
in01 out01 p2
```

- `j`: received report count in hexadecimal, wrapping after `ffff`. It resets on
  reconnect. If it stays at zero while moving the stick, no input packets arrived.
- `l`: actual/descriptor report length in decimal, including any report ID byte.
  An unknown report ID shows an expected length of zero.
- `d+` / `d-`: the latest packet decoded successfully / did not decode. Before
  the first packet, `d-` and `in--` mean no input has been decoded yet.
- `r+` / `r-`: the last request for the next USB report succeeded / failed.
  Success means the transfer was queued; it does not prove packets are arriving.
- `in`: decoded controls; `--` means the latest packet could not be decoded.
- `out`: combined controls submitted to the output core after routing and menu
  capture. This is a software state, not a measurement of the DB9 signals.
- `p`: enabled joystick ports: `0` none, `1` first, `2` second, `3` both.
- `wait`: input is captured by the menu or waiting for a neutral report after
  leaving it. Centre the stick and release all buttons; move it and centre it
  again if it sends reports only when controls change.

Controls are hexadecimal bit masks: up `01`, down `02`, left `04`, right `08`,
fire 1 `10`, fire 2 `20`, fire 3 `40`; combinations add together. Neutral is `00`.
The input diagnostics follow the first mounted controller slot; output includes
all controllers. Reconnect resets that controller's counters. Updates are limited
to ten per second and Bluetooth pairing messages take priority on the fourth row.

Before the first report, the fourth row instead shows the USB identity and
initialization status, for example `usb 054c:0268 s+`. The status is `s-` for a
generic device needing no startup command, `sp` pending submission, `s?` awaiting
completion, `s+` completed, or `s!` failed. Completion alone does not prove input
has started; check that the `j` counter advances when moving the stick.

With a Bluetooth gamepad and no USB joystick connected, the rows show:

```text
b002a l11/11 d+
in01 out01 p2
```

`b` counts Bluetooth reports; the other fields have the same meanings as above.
Lengths include a Report ID when the HID descriptor uses one. Bluetooth input
arrives through LE notifications or Classic HID packets, so there is no USB `r` field. USB joystick
diagnostics take priority if both are connected; unplug the USB joystick when
checking Bluetooth reports. A Classic gamepad takes precedence over an LE gamepad
in diagnostics. The first line's USB device counts exclude Bluetooth.

## Validation

Temporary native checks cover descriptor parsing, malformed/truncated reports,
report IDs, settings migration, menu capture, mode changes, disconnects and the
actual controller GPIO output. REV5 builds pass for Pico W USB + Bluetooth
(Release and Debug) and USB-only Pico (Release), with a REV4 Release regression
build. Native checks cover concurrent mouse/joystick output, the REV5 pin map,
port 2 disable, capture, source disconnects and settings migration. The Competition
Pro works in Great Giana Sisters on REV5 with `0.3.0-dev-12-g4da9d14`. Exhaustive
direction/diagonal/fire checks, unplugging, menu entry and returning to mouse mode
still need hardware validation. No new tests are checked in.

The connected Competition Pro Extra (`0079:181c`, identifying as
`SPEEDLINK COMPETITION PRO Game Controller for Android`) was inspected on Linux.
Its digital stick reports X/Y values of 0, 128 and 255; its advertised hat remained
centred. Native checks using its actual descriptor and captured axis values pass
for neutral, all four directions and all four diagonals. All four physical buttons
produced input events; the initial generic HID trial mapped only Button 1 to fire.
This Linux capture verified the generic input decoder; the subsequent hardware
test used the PS3-compatible USB path described below.

Hardware testing of `0.3.0-dev-10-g7c4f8fa` detected the Competition Pro (`j:01`),
but Amiga Test Kit showed no activity on port 2 or on port 1 through the working
mouse cable with port 1 set to USB joystick.
The diagnostic build then showed `j0000 l00/49 d- r+` even while moving the stick,
connected directly to the AmigaHID board. No reports arrived, and the advertised
49-byte layout differs from the 9-byte layout captured on Linux. The user then
confirmed successful gameplay with the PS3 initialization build. This supports
the PS3-mode explanation, though the USB identity was not read back directly.

Temporary checks cover short/empty reports,
report IDs, receive-request failures, reconnects, menu capture, display rate
limiting and Bluetooth pairing-message priority. Synthetic PS3 reports cover
identity/layout guards, initialization queue retry, completion/failure, reconnect,
all stick directions, D-pad inputs and the four face buttons. No new tests are
checked in.

Temporary LE checks use the published
[182-byte Stadia Bluetooth descriptor](https://github.com/libsdl-org/SDL/issues/7224#issuecomment-1445457085).
They cover D-pad and left-stick directions, A/fire, neutral releases, truncated
reports, report-ID-zero handling, multiple HID services, disconnect/reconnect,
queue overflow and 50,000 mixed gamepad/disconnect events. The button mapping
agrees with [SDL's Stadia driver](https://github.com/libsdl-org/SDL/blob/main/src/joystick/hidapi/SDL_hidapi_stadia.c).
Existing boot keyboard/mouse discovery paths, settings persistence, joystick
routing and OLED diagnostics also pass native checks. On 2026-09-28 the user
confirmed Stadia pairing (`bt c0 le:ready j1`) and D-pad/A-button input in Amiga
Test Kit on port 2, using Pico W/REV5 firmware `0.3.0-dev-13-gde9ae63`.

The PS3 startup transfer is feature report `f4`, payload `42 0c 00 00`, as used
by the [USB Host Shield PS3 driver](https://github.com/felis/USB_Host_Shield_2.0/blob/master/PS3USB.cpp#L444).
A [Competition Pro adapter implementation](https://www.hackster.io/DocSnyderde/connect-usb-joystick-to-commodore-c64-2fb5ba)
uses that driver and maps the physical fire buttons to the PS3 face buttons.

The parser follows [USB HID 1.11](https://www.usb.org/sites/default/files/hid1_11.pdf)
and the [HID Usage Tables](https://www.usb.org/sites/default/files/hut1_2.pdf).
Output uses the digital joystick pin assignments in Commodore's
[Amiga Hardware Reference Manual, Appendix E](https://www.theflatnet.de/pub/cbm/amiga/AmigaDevDocs/hard_e.html).

## Gamepad settings

The OLED menu now selects D-pad and stick together (default), D-pad only, or
stick only. Stick deadzone selects the central 25%, 50% (default), or 75% of
travel; directions activate outside that range. A wider deadzone requires more
stick movement. These settings apply to USB and Bluetooth controllers.

Each of seven output buttons has an Auto mapping, a HID button number 1–16, or
Disabled. The first three are the ordinary joystick buttons; the other four
are retained for CD32 output. Mappings are global across connected controllers.
Auto retains the tested PS4 Cross/Circle/Square and Stadia A/B/X mapping.
PS4's additional defaults are Triangle, L1, R1, Options; Stadia's are Y, L1,
R1, Menu. The Competition Pro retains all four face buttons as fire 1.

For custom mappings, PS4 HID numbers are Square=1, Cross=2, Circle=3,
Triangle=4, L1=5, R1=6, L2=7, R2=8, Share=9, Options=10.
Stadia uses A=1, B=2, X=4, Y=5, L1=7, R1=8, Menu=12.
**PS4 mouse controls** selects Touchpad + shoulders (the tested default),
Touchpad only, or Off, so shoulders can be dedicated to gamepad use.

Save and exit applies these choices. Release held controls before resuming.
Schema 5 preserves older settings and selects the previous direction, deadzone,
and mouse defaults. Diagnostics now use three hexadecimal digits; extra output
bits are fourth button `080`, rewind `100`, forward `200`, and play `400`.
Hardware validation of the new settings is pending.

## CD32 pad mode

Keep Controller port 1 as Mouse and select **Controller port 2: CD32 pad**, then
Save and exit. In Amiga Test Kit select **CD32 Pad** for Amiga port 2 (F2 cycles
its type). Check **Pad Detected**, directions, all seven buttons and release states.
Port 1 can also select CD32; REV2/REV4 support CD32 on port 1 only. Both enabled
controller ports currently receive the same combined gamepad state.

| CD32 button | PS4 default | Stadia default |
| --- | --- | --- |
| Red | Cross | A |
| Blue | Circle | B |
| Green | Square | X |
| Yellow | Triangle | Y |
| Rewind | L1 | L1 |
| Forward | R1 | R1 |
| Play/Pause | Options | Menu |

The seven Gamepad mapping settings override these defaults. To use PS4 shoulders
only for CD32, select **PS4 mouse controls: Touchpad only**; touch movement and
pad-click remain available on the mouse port. The previous mouse-button mapping
remains the default until changed.

CD32 uses Amiga pin 5 as select, pin 6 as clock and pin 9 as serial data. PIO
handles both data and fire/clock ownership, with open-drain outputs; the select
line is never driven in CD32 mode. Each read snapshots all buttons and supplies
the identification bits after them. With select high, Red and Blue behave as
ordinary joystick buttons. CD32 mode does not provide the third ordinary button
on pin 5, because that pin belongs to the Amiga's select signal.

PIO1 supplies two state machines per port and shares 25 instructions between
ports. PIO0 remains available to CYW43. Clock handling continues through CPU
interrupts and flash lockout. Direction pins remain serviced by the output core.
Reference: [Amiga Test Kit's read_gamepad implementation](https://github.com/keirf/amiga-stuff/blob/master/testkit/joymouse.c).

Temporary simulation of the assembled PIO program passes all 128 button patterns,
phase offsets, ID/tail bits, snapshot changes and interrupted reads. Native GPIO
checks cover mode changes, capture and concurrent mouse/CD32 routing. These are
software checks; CD32 electrical timing and recognition on the Amiga await the
first hardware test. No new tests are checked into the repository.

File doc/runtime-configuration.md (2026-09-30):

# Runtime configuration

The `features` branch adds a settings menu to the existing USB and Bluetooth
firmware. It works with the OLED on REV2, REV4 and REV5 boards. Board selection and
GPIO wiring remain build-time options.

## Open and use the menu

Hold **F12 for one second**, then release it. USB and Bluetooth keyboards use
the same menu. Press Up/Down to select an item, Left/Right to change its value,
and Enter to change a value or activate an action. **Save and exit** writes
settings to flash and applies them. **Esc** or **Cancel changes** discards edits.

Factory defaults changes the values in the editor; select Save and exit to
apply and preserve them. Values are not previewed while editing.

While the menu is open, keyboard, mouse and joystick input is captured locally.
Previously forwarded keys, buttons and directions are released, and queued mouse
motion is discarded. After closing, release held keys/buttons and centre the
gamepad before using them again. The firmware
version stays visible, and normal status/pairing text is restored on exit.

| Setting | Choices | Default |
| --- | --- | --- |
| Menu key | F12, F11, Application/Menu | F12 |
| Menu entry | Hold for one second, boot only | Hold |
| Right GUI key | Right Amiga, hold to open menu, disabled | Right Amiga |
| Mouse wheel | TankMouse/Cocolino, off | TankMouse/Cocolino |
| Wheel direction | Normal, reverse vertical | Normal |
| Mouse step interval | 300, 200, 150, 100 microseconds | 300 |
| Display | Status, HID diagnostics, mouse diagnostics, off | Status |
| Watchdog | Off, 2 seconds, 5 seconds | Off |
| Controller port 1 | Mouse, Joystick, CD32 pad | Mouse |
| Controller port 2 (REV5 only) | Off, Joystick, CD32 pad | Joystick |

The selected menu key is reserved for configuration while a working OLED is
present. The Right GUI setting affects the right Windows/Command modifier;
Application/Menu retains its existing Right Amiga mapping unless selected as
the menu key. The default Amiga reset chord is unchanged.

On REV5, mouse on port 1 and joystick on port 2 work simultaneously by default.
Joystick uses a supported USB or Bluetooth HID controller's stick/D-pad and
up to three fire buttons. See [joystick setup](joystick.md) for mappings and validation.
Port 2 can be disabled with its own setting. Selecting Joystick on port 1
disables mouse input; if both ports are set to joystick, they mirror the same
combined controller state. Keyboard input continues normally in all modes.
REV2/REV4 builds expose only the port 1 setting and do not drive port 2.
Release the gamepad controls and mouse buttons after changing modes. See
[joystick mode](joystick.md) for supported formats and testing instructions.

Faster mouse intervals change the rate at which queued movement is emitted,
not mouse sensitivity. They require testing with the connected Amiga. The
watchdog restarts the Pico if its main loop stops completing; it does not
independently detect a stalled mouse core. It starts after normal initialization
and pauses when a debugger halts the CPU. A watchdog reboot is reported on the
OLED and UART.

HID diagnostics show mount/receive status on the third line. With a supported USB
gamepad connected, the third and fourth lines show its report count, packet length,
decode result and routed controls; see [joystick diagnostics](joystick.md#diagnosing-missing-input).
Mouse diagnostics
update the fourth line at most ten times per second; Bluetooth pairing messages
take precedence. Turning the display off blanks normal status, but the menu
still appears when invoked. A missing or failed OLED prevents menu capture, so
normal input continues. Right GUI falls back to Right Amiga if it was assigned
to an unavailable menu; an explicitly disabled Right GUI remains disabled.

## Recover settings

During the **first ten seconds of input servicing after startup**, F12 always
opens the menu, even if another menu key or boot-only entry was saved.

For recovery, hold **F12 and Esc together for two seconds** during that window.
This applies factory defaults in RAM, disables the optional watchdog, enables
the display, and opens the menu. Select **Save and exit** to retain the defaults
across power cycles. Bluetooth pairing data is preserved. A connected USB
keyboard is the most direct way to enter this recovery mode at startup.

Invalid or missing saved settings automatically use defaults. If the display
itself has failed, the firmware continues using saved settings without a menu.

## Storage and validation

Settings use schema version 7 and a CRC32. Two alternating 4 KiB sectors keep
the previous valid record intact while a new record is erased/programmed. On
boot, the newest valid record is selected, including across sequence rollover.
Unchanged saves do not erase flash. Failed saves leave the menu open and do not
apply the edited values.

The last 16 KiB of flash is reserved by a linker assertion: two settings sectors
followed by the SDK's two Bluetooth pairing sectors. USB-only and Bluetooth
builds use the same layout. Settings writes run through the SDK's flash-safe
execution API with core1 registered for lockout. Normal UF2 updates below this
region preserve settings; erasing the entire flash removes them.

Schema 1–6 records are migrated in RAM, preserving existing settings,
including the watchdog timeout and any saved port 1 choice. Port 1 defaults to
Mouse when migrating schema 1, which had no port setting. The new port 2 option
defaults to Joystick on REV5 and Off on other revisions. If an earlier trial
saved port 1 as USB joystick, change that setting to Mouse for simultaneous
mouse/joystick use. The next explicit save writes schema 7. Unknown schemas are
rejected, falling back to a compatible record or defaults.

Temporary native checks cover CRC/schema validation, interrupted writes and
erases, sequence rollover, schema migration, save/cancel, menu capture and held-key
release, recovery, display caching and watchdog control. The menu and persistence
of a saved 5-second watchdog timeout have been confirmed on Pico W/REV5 across
power loss (using the earlier REV4 firmware). Joystick input is confirmed on REV5
with Competition Pro, Stadia and PS4 controllers; see [validation details](joystick.md).
Recovery and an actual watchdog-triggered restart still need hardware validation.
No new tests are checked into the repository.

## Bluetooth controls

Pico W Bluetooth builds provide **Bluetooth: On/Off** and **BT pairing policy**.
Save and exit applies the radio setting without rebooting. Off releases connected
inputs; saved bonds remain available when it is turned on again. Automatic is the
existing discovery/pairing behavior. Paired devices only accepts stored Classic
keys and resolves LE addresses against the bond database, including private addresses.

**Pair for 2 minutes** temporarily allows new devices in paired-only mode. It is
an immediate action using the saved radio setting; enable and save Bluetooth first.
Existing connections remain active. **Forget BT devices** requires Enter twice,
disconnects devices, clears Classic and LE bonds, and restarts Bluetooth. In
paired-only mode, use Pair afterwards to enrol devices again. These actions do
not save unrelated menu edits. USB-only builds omit these menu items.

Settings schema 4 migrates schemas 1–3, preserving previous choices and defaulting
Bluetooth to On with Automatic pairing. Hardware validation is pending.

## Keyboard mappings

**Keyboard preset** keeps the original QWERTY mapping, swaps Y/Z, or swaps A/Q
and W/Z. These are physical letter-key permutations, not full national AmigaOS
keymaps; select the matching locale on the Amiga for punctuation and accents.
**ISO extra key** can route the key beside left Shift to the Amiga ISO key rather
than the original backslash mapping. **Amiga Help key** selects Insert (default),
Home, Page Up, F11, or None; **Amiga Delete key** selects Delete (default),
Backspace, or None. Moving Help/Delete removes their old Insert/Delete bindings.
A key reserved for entering the menu continues to open the menu.

Eight custom slots override the preset and Help/Delete choices. Select a slot,
select **Custom source key**, press Enter, then press the source key. Escape
cancels learning. Use **Custom Amiga key** to choose the destination with Left/Right,
or Disabled to suppress it. **Clear custom slot** restores the normal mapping.
Save and exit applies and stores all changes. Source keys exclude modifiers and
reserved menu/recovery keys; destination choices include Amiga modifiers. Right
GUI keeps its separate setting and the default Ctrl-Amiga-Amiga chord is preserved.
Two keys or keyboards mapped to the same Amiga key retain it until both release.

Schema 6 migrates schemas 1–5 with original keyboard behavior and empty custom
slots. New keyboard settings still require hardware validation.

## CD32 and migration

Both controller-port menus now include CD32 pad; ordinary joystick remains the
port 2 default on REV5. See [CD32 setup and mappings](joystick.md#cd32-pad-mode).
Schema 7 adds this mode and reads every previous settings schema. Migration keeps
your watchdog, port choices, keyboard behavior and wheel settings. New choices
use the previously tested defaults. Save and exit commits the migrated record.
Hardware validation of all four new feature groups is pending.

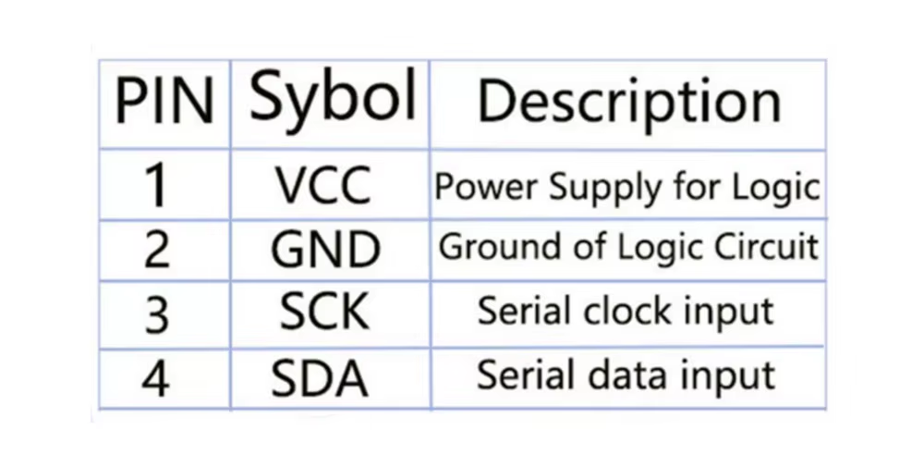
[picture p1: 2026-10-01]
kicad_r6/review/oled-pinout.png

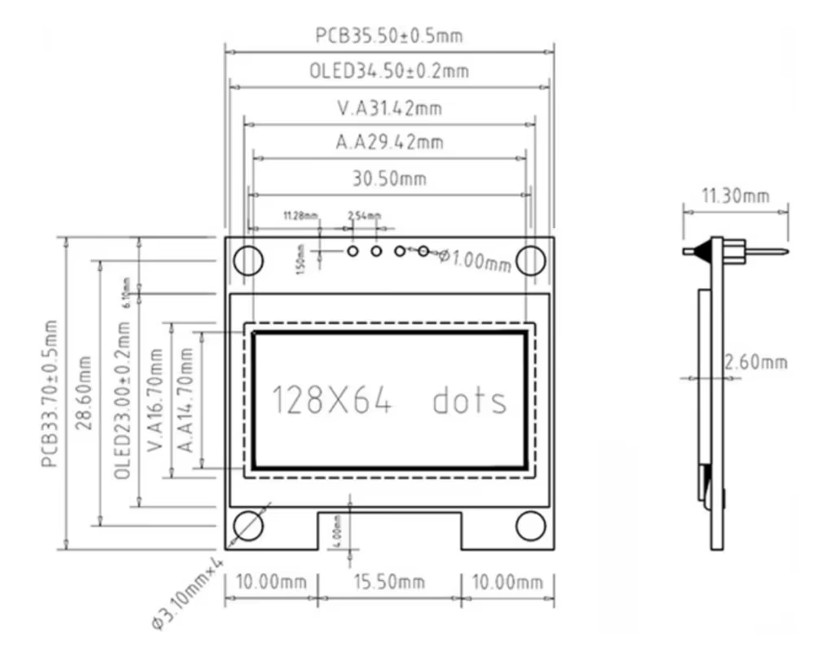
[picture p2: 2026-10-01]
kicad_r6/review/oled-dimensions.png

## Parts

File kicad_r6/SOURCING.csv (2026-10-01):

Reference | LCSC Part # | Manufacturer | MPN | Stock at check | Checked UTC | Source | Datasheet | Fit notes
U2 | C44508 | TI | SN74CBTD3861DBQR | 117 | 2026-09-30T02:28:45.849330+00:00 | https://www.lcsc.com/product-detail/C44508.html | https://datasheet.lcsc.com/datasheet/pdf/10418c54070348a4b7d34e5e4823055e.pdf?productCode=C44508 | DBQ SSOP-24 selected for stocked C44508; 0.635 mm pitch. Not PWR/TSSOP.
U3 | C44508 | TI | SN74CBTD3861DBQR | 117 | 2026-09-30T02:28:45.849330+00:00 | https://www.lcsc.com/product-detail/C44508.html | https://datasheet.lcsc.com/datasheet/pdf/10418c54070348a4b7d34e5e4823055e.pdf?productCode=C44508 | DBQ SSOP-24 selected for stocked C44508; 0.635 mm pitch. Not PWR/TSSOP.
J1 | C706880 | XKB Connection | X6511WV-08H-C60D30 | 610 | 2026-09-30T02:28:46.174334+00:00 | https://www.lcsc.com/product-detail/C706880.html | https://datasheet.lcsc.com/datasheet/pdf/6a4628c39c71d59f65cfdff6271ca694.pdf?productCode=C706880 | Standard package/pitch and electrical value match.
J2 | C706878 | XKB Connection | X6511WV-06H-C60D30 | 400 | 2026-09-30T02:28:46.556337+00:00 | https://www.lcsc.com/product-detail/C706878.html | https://datasheet.lcsc.com/datasheet/pdf/b62a5c2559ab497eec58d25252ac0a3a.pdf?productCode=C706878 | Standard package/pitch and electrical value match.
J3 | C7509546 | CONNFLY Elec | DS1023-1x4SF11 | 2530 | 2026-09-30T02:28:46.889340+00:00 | https://www.lcsc.com/product-detail/C7509546.html | https://datasheet.lcsc.com/datasheet/pdf/e746529444b0a48d4f291628523ddcfb.pdf?productCode=C7509546 | Single-row female socket, 2.54 mm pitch, 8.5 mm body height.
J4 | C7279912 | JST | UBA-4R-D14-4D(LF)(SN) | 265 | 2026-09-30T02:28:47.333345+00:00 | https://www.lcsc.com/product-detail/C7279912.html | https://datasheet.lcsc.com/datasheet/pdf/f64d925fe87e64a5b6cfc8f40b7aa44b.pdf?productCode=C7279912 | JST UBA-4R-D14-4D: 13.14 mm shell pitch, 2.71 mm setback, 7/2 mm signal pitch; body/3D outline approximate.
J5 | C50380980 | LCKELEC | LCK-205A09FJ2A00B1A | 1935 | 2026-09-30T02:28:47.703348+00:00 | https://www.lcsc.com/product-detail/C50380980.html | https://datasheet.lcsc.com/datasheet/pdf/98ad6adf9b8970a112421d2b06a83c6e.pdf?productCode=C50380980 | 25 mm mount spacing; 2.77 x 2.84 mm pins; signal drills enlarged to 1.10 mm. Body/3D outline approximate.
J6 | C50380980 | LCKELEC | LCK-205A09FJ2A00B1A | 1935 | 2026-09-30T02:28:47.703348+00:00 | https://www.lcsc.com/product-detail/C50380980.html | https://datasheet.lcsc.com/datasheet/pdf/98ad6adf9b8970a112421d2b06a83c6e.pdf?productCode=C50380980 | 25 mm mount spacing; 2.77 x 2.84 mm pins; signal drills enlarged to 1.10 mm. Body/3D outline approximate.
J7 | C7428703 | HOOYA | DIN-603 | 225 | 2026-09-30T02:28:48.021351+00:00 | https://www.lcsc.com/product-detail/C7428703.html | https://datasheet.lcsc.com/datasheet/pdf/5838b0b96a2a0bc17e3a0f9820189c0a.pdf?productCode=C7428703 | DIN603 hole geometry and pin numbering verified against drawing and LCSC EasyEDA library.
J8 | C706876 | XKB Connection | X6511WV-04H-C60D30 | 26130 | 2026-09-30T02:28:48.324354+00:00 | https://www.lcsc.com/product-detail/C706876.html | https://datasheet.lcsc.com/datasheet/pdf/53deca84ded28e9494fb227a5f6cd971.pdf?productCode=C706876 | Standard package/pitch and electrical value match.
J9 | C706874 | XKB Connection | X6511WV-02H-C60D30 | 17940 | 2026-09-30T02:28:48.676358+00:00 | https://www.lcsc.com/product-detail/C706874.html | https://datasheet.lcsc.com/datasheet/pdf/418a918ff249aca424d0b4f258558b75.pdf?productCode=C706874 | Standard package/pitch and electrical value match.
JP1 | C55099243 | SHOU HAN | PZ2.0-1x3PZZ-L8.7 | 3850 | 2026-09-30T02:28:49.041361+00:00 | https://www.lcsc.com/product-detail/C55099243.html | https://datasheet.lcsc.com/datasheet/pdf/61dd52b5d268e3df19a6c4df85bf5f0b.pdf?productCode=C55099243 | Standard package/pitch and electrical value match.
D1 | C8598 | JSCJ | B5819W SL | 229920 | 2026-09-30T02:28:49.340364+00:00 | https://www.lcsc.com/product-detail/C8598.html | https://datasheet.lcsc.com/datasheet/pdf/4ac2c059be7c462694ab0715ce987a85.pdf?productCode=C8598 | Standard package/pitch and electrical value match.
F1 | C75464 | BOURNS | MF-NSMF050-2 | 59460 | 2026-09-30T02:28:49.739368+00:00 | https://www.lcsc.com/product-detail/C75464.html | https://datasheet.lcsc.com/datasheet/pdf/9de05d43c1e248c08c092bceb30077bc.pdf?productCode=C75464 | Standard package/pitch and electrical value match.
C1 | C14663 | YAGEO | CC0603KRX7R9BB104 | 8519800 | 2026-09-30T02:28:50.076371+00:00 | https://www.lcsc.com/product-detail/C14663.html | https://datasheet.lcsc.com/datasheet/pdf/23ccee80ee542e7cf156a772bb589942.pdf?productCode=C14663 | 50 V selected, exceeds 16 V minimum.
C2 | C14663 | YAGEO | CC0603KRX7R9BB104 | 8519800 | 2026-09-30T02:28:50.076371+00:00 | https://www.lcsc.com/product-detail/C14663.html | https://datasheet.lcsc.com/datasheet/pdf/23ccee80ee542e7cf156a772bb589942.pdf?productCode=C14663 | 50 V selected, exceeds 16 V minimum.
C5 | C14663 | YAGEO | CC0603KRX7R9BB104 | 8519800 | 2026-09-30T02:28:50.076371+00:00 | https://www.lcsc.com/product-detail/C14663.html | https://datasheet.lcsc.com/datasheet/pdf/23ccee80ee542e7cf156a772bb589942.pdf?productCode=C14663 | 50 V selected, exceeds 16 V minimum.
C3 | C15850 | Samsung Electro-Mechanics | CL21A106KAYNNNE | 594040 | 2026-09-30T02:28:50.482375+00:00 | https://www.lcsc.com/product-detail/C15850.html | https://datasheet.lcsc.com/datasheet/pdf/02336ea48ea44ca18c72517dd3cb7b47.pdf?productCode=C15850 | 25 V X5R selected, exceeds 10 V minimum.
C4 | C970688 | DMBJ | RVT1A151M0605 150UF 10V | 520 | 2026-09-30T02:28:50.913379+00:00 | https://www.lcsc.com/product-detail/C970688.html | https://datasheet.lcsc.com/datasheet/pdf/f0a865b841864fb1f67292a6eb3bf84a.pdf?productCode=C970688 | Standard package/pitch and electrical value match.
R1 | C23162 | UNI-ROYAL | 0603WAF4701T5E | 13626200 | 2026-09-30T02:28:51.371383+00:00 | https://www.lcsc.com/product-detail/C23162.html | https://datasheet.lcsc.com/datasheet/pdf/0a975aaa49b7c97f38a963127be4a823.pdf?productCode=C23162 | Standard package/pitch and electrical value match.
R2 | C23162 | UNI-ROYAL | 0603WAF4701T5E | 13626200 | 2026-09-30T02:28:51.371383+00:00 | https://www.lcsc.com/product-detail/C23162.html | https://datasheet.lcsc.com/datasheet/pdf/0a975aaa49b7c97f38a963127be4a823.pdf?productCode=C23162 | Standard package/pitch and electrical value match.
RN1 | C192513 | PANASONIC | EXB38V103JV | 53500 | 2026-09-30T02:28:51.779387+00:00 | https://www.lcsc.com/product-detail/C192513.html | https://datasheet.lcsc.com/datasheet/pdf/45e874bd934a49da039ce7e7afe0034c.pdf?productCode=C192513 | Standard package/pitch and electrical value match.
RN2 | C192513 | PANASONIC | EXB38V103JV | 53500 | 2026-09-30T02:28:51.779387+00:00 | https://www.lcsc.com/product-detail/C192513.html | https://datasheet.lcsc.com/datasheet/pdf/45e874bd934a49da039ce7e7afe0034c.pdf?productCode=C192513 | Standard package/pitch and electrical value match.
RN3 | C192513 | PANASONIC | EXB38V103JV | 53500 | 2026-09-30T02:28:51.779387+00:00 | https://www.lcsc.com/product-detail/C192513.html | https://datasheet.lcsc.com/datasheet/pdf/45e874bd934a49da039ce7e7afe0034c.pdf?productCode=C192513 | Standard package/pitch and electrical value match.
RN4 | C192513 | PANASONIC | EXB38V103JV | 53500 | 2026-09-30T02:28:51.779387+00:00 | https://www.lcsc.com/product-detail/C192513.html | https://datasheet.lcsc.com/datasheet/pdf/45e874bd934a49da039ce7e7afe0034c.pdf?productCode=C192513 | Standard package/pitch and electrical value match.
RN5 | C192513 | PANASONIC | EXB38V103JV | 53500 | 2026-09-30T02:28:51.779387+00:00 | https://www.lcsc.com/product-detail/C192513.html | https://datasheet.lcsc.com/datasheet/pdf/45e874bd934a49da039ce7e7afe0034c.pdf?productCode=C192513 | Standard package/pitch and electrical value match.
RN6 | C192513 | PANASONIC | EXB38V103JV | 53500 | 2026-09-30T02:28:51.779387+00:00 | https://www.lcsc.com/product-detail/C192513.html | https://datasheet.lcsc.com/datasheet/pdf/45e874bd934a49da039ce7e7afe0034c.pdf?productCode=C192513 | Standard package/pitch and electrical value match.
RN7 | C192513 | PANASONIC | EXB38V103JV | 53500 | 2026-09-30T02:28:51.779387+00:00 | https://www.lcsc.com/product-detail/C192513.html | https://datasheet.lcsc.com/datasheet/pdf/45e874bd934a49da039ce7e7afe0034c.pdf?productCode=C192513 | Standard package/pitch and electrical value match.
RN8 | C192513 | PANASONIC | EXB38V103JV | 53500 | 2026-09-30T02:28:51.779387+00:00 | https://www.lcsc.com/product-detail/C192513.html | https://datasheet.lcsc.com/datasheet/pdf/45e874bd934a49da039ce7e7afe0034c.pdf?productCode=C192513 | Standard package/pitch and electrical value match.
RN9 | C192513 | PANASONIC | EXB38V103JV | 53500 | 2026-09-30T02:28:51.779387+00:00 | https://www.lcsc.com/product-detail/C192513.html | https://datasheet.lcsc.com/datasheet/pdf/45e874bd934a49da039ce7e7afe0034c.pdf?productCode=C192513 | Standard package/pitch and electrical value match.
RN10 | C192513 | PANASONIC | EXB38V103JV | 53500 | 2026-09-30T02:28:51.779387+00:00 | https://www.lcsc.com/product-detail/C192513.html | https://datasheet.lcsc.com/datasheet/pdf/45e874bd934a49da039ce7e7afe0034c.pdf?productCode=C192513 | Standard package/pitch and electrical value match.
U1 | C7203003 | Raspberry Pi | Raspberry Pi Pico W | 855 | 2026-09-30T04:30:40.668988+00:00 | https://www.lcsc.com/product-detail/C7203003.html | https://datasheets.raspberrypi.com/picow/pico-w-datasheet.pdf | Pico W (RP2040), selected per user. Official Pico W and Pico 2 W figures 2/5 match: 40 pins, USB TP1-3, SWD pads, four USB-shell solder lands. Pico 2 W remains a footprint-compatible alternative requiring pico2_w firmware; fitted Pico W requires pico_w firmware.

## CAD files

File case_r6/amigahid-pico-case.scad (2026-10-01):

// AmigaHID r6 enclosure. Derived from ../amigahid-pico-case; YAPP MIT library.
// World X = KiCad X, world Y = 68 - KiCad Y. All dimensions in mm.
include <pcb-mechanics.scad>

/* [Output] */
view = "print"; // [print,base,lid,assembled,fit,collision]
oled = true;
external_power_opening = false;
a500_cable_opening = false;
/* [Fit adjustments] */
pcb_clearance = 0.6;
port_clearance = 0.6; // per side, beyond supplier nominal dimensions
pilot_diameter = 1.7; // M2 tapped pilot; use M2x4 nylon screws
// Board top to underside of the OLED PCB, using H1-H4 nylon spacers.
oled_standoff = 12;
oled_board_thickness = 1.2;
oled_glass_height = 2.6;
oled_window_y_trim = 0;
// Inputs used by YAPP overrides must exist before its include.
ox = 2.2 + pcb_clearance;
oy = 2.2 + 3;
board_top = 3 + 3 + board_t;
ceiling = 3 + 6 + 15;
case_x = board_x + 2*pcb_clearance + 2*2.2;
case_y = board_y + 3 + pcb_clearance + 2*2.2;
case_z = ceiling + 2.5;
oled_corner = [h1[0]-2.5, h1[1]+2.55];
window_xy = [oled_corner[0]+17.75, oled_corner[1]-17.4+oled_window_y_trim];
include <vendor/YAPP_Box/YAPPgenerator_v3.scad>

/* [Hidden] */
pcbLength = board_x;
pcbWidth = board_y;
pcbThickness = board_t;
standoffHeight = 3;
standoffDiameter = 4.4;
standoffPinDiameter = 2;
standoffHoleSlack = 0.2;
paddingFront = pcb_clearance;
paddingBack = pcb_clearance;
paddingLeft = 3; // air gap beyond the antenna end
paddingRight = pcb_clearance;
wallThickness = 2.2;
basePlaneThickness = 3;
lidPlaneThickness = 2.5;
baseWallHeight = 6; // low split lets connectors drop into the open base
lidWallHeight = 15;
ridgeHeight = 4.5;
ridgeSlack = 0.25;
ridgeGap = 0.25;
yappSnapOuterSkin = 0.8; // blind snap pockets: continuous exterior wall
yappSnapRadialSlack = 0.15; // clearance between pocket and shortened base bump
roundRadius = 2;
boxType = 3;
renderQuality = 12;
previewQuality = 8;
printMessages = false;
showOrientation = false;
showPCB = false;
showSideBySide = view == "print";
onLidGap = 0;
printBaseShell = view != "lid";
printLidShell = view != "base" && view != "fit";
printSwitchExtenders = false;
printDisplayClips = false;
colorBase = "SlateGray";
colorLid = "Gainsboro";
alphaBase = 1;
alphaLid = 1;

assert(ceiling - (board_top+oled_standoff+oled_board_thickness+oled_glass_height) >= 0.4,
       "OLED glass needs at least 0.4 mm clearance under lid");
assert(port_clearance >= 0.3);

// Connector cutouts use PCB coordinates, with Z measured above the main PCB.
// +X wall: mini-DIN opening accepts a <=14.4 mm plug moulding; USB uses full shell.
cutoutsFront = [
    [j7[1], 6.55, 0, 0, 7.5, yappCircle, 0, 0, yappCenter, yappCoordPCB],
    [usb_y, 3.545, 14.5+2*port_clearance, 7.09+2*port_clearance,
     0.5, yappRoundedRect, 0, 0, yappCenter, yappCoordPCB]
];
// +Y wall: full DE9 flange/body relief permits top-down PCB installation.
// Centres come from the two shell mounting pads, NOT the footprint origin.
cutoutsRight = [for (x=de9_centres)
    [x, 6.25, 30.8+2*port_clearance, 12.5+2*port_clearance,
     0.4, yappRoundedRect, 0, 0, yappCenter, yappCoordPCB]
];
// Optional external 5V pigtail: J9 remains a header, not a panel power jack.
cutoutsLeft = external_power_opening ? [
    [j9[0]+1.27, 5, 9, 7, 1.5, yappRoundedRect, 0, 0, yappCenter, yappCoordPCB]
] : [];
cutoutsBack = a500_cable_opening ? [
    [j1[1]-8.89, 5, 6, 7, 1.5, yappRoundedRect, 0, 0, yappCenter, yappCoordPCB]
] : [];
cutoutsLid = oled ? [
    [window_xy[0], window_xy[1], 32.22, 17.5, 0.5,
     yappRoundedRect, 0, 0, yappCenter, yappCoordPCB]
] : [];
// Snap locations avoid the connector apertures and the antenna end.
snapJoins = [[20+oy,6,yappBack], [55+oy,6,yappBack],
             [30+ox,6,yappLeft], [44+ox,6,yappLeft]];
pcbStands = [];
connectors = [];

// Only H5/H6 support the main board. H1-H4 carry the OLED on separate spacers.
module hookBaseInside() {
    for (h=[h5,h6]) translate([paddingBack+h[0],paddingLeft+h[1],-0.01])
        difference() {
            cylinder(d=4.4,h=standoffHeight+0.01,$fn=48);
            translate([0,0,-0.02]) cylinder(d=pilot_diameter,h=standoffHeight+0.06,$fn=36);
        }
}

// Inspection-only envelopes. Never included in printable base/lid exports.
module pcb_envelope() {
    translate([ox,oy,basePlaneThickness+standoffHeight+0.01]) difference() {
        cube([board_x,board_y,board_t-0.01]);
        translate([10,-0.01,-0.01]) cube([14,9.01,board_t+0.02]);
        for(h=[h1,h2,h3,h4,h5,h6]) translate([h[0],h[1],-0.01])
            cylinder(d=(h==h5||h==h6)?2.2:3.2,h=board_t+0.02,$fn=32);
    }
}
module hardware_envelopes() {
    color("ForestGreen") pcb_envelope();
    // Supplier full-body envelopes, conservative at connector corners.
    for(x=de9_centres) color("Silver")
        translate([ox+x-15.4,oy+board_y-9.8,board_top]) cube([30.8,18.91,12.5]);
    color("Silver") translate([ox+57.28,oy+j7[1]-7.1,board_top]) cube([12.8,14.2,13.1]);
    color("Silver") translate([ox+55.77,oy+usb_y-7.25,board_top]) cube([15.22,14.5,7.09]);
    color("SeaGreen") translate([ox+u1[0]-10.5,oy+u1[1]-25.5,board_top+0.1]) cube([21,51,4.0]);
    if(oled) {
        color("DarkGreen") translate([ox+oled_corner[0],oy+oled_corner[1]-33.7,board_top+oled_standoff]) cube([35.5,33.7,oled_board_thickness]);
        color("MidnightBlue") translate([ox+window_xy[0]-17.25,oy+window_xy[1]-11.5,board_top+oled_standoff+oled_board_thickness]) cube([34.5,23,oled_glass_height]);
    }
}

if(view=="collision") intersection() { let($preview=true) YAPPgenerate(); hardware_envelopes(); }
else {
    if(view=="assembled") let($preview=true) YAPPgenerate();
    else if(view=="lid") translate([0,-(case_y+10+shiftLid),0]) YAPPgenerate();
    else YAPPgenerate();
    if(view=="fit") hardware_envelopes();
}
echo("r6 case outside XYZ",[case_x,case_y,case_z]);
echo("r6 PCB top Z / OLED glass top Z",board_top,board_top+oled_standoff+oled_board_thickness+oled_glass_height);

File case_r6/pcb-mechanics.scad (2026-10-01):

// Generated by tools/extract_pcb.py from kicad_r6; units mm.
board_x = 70;
board_y = 68;
board_t = 1.6;
h1 = [35.75, 34.65];
h2 = [66.25, 34.65];
h3 = [35.75, 6.049999999999997];
h4 = [66.25, 6.049999999999997];
h5 = [2.7, 5.0];
h6 = [53.3, 45.5];
j1 = [3.0, 52.0];
j3 = [47.03, 35.66];
j4 = [58.0, 14.0];
j5 = [12.0, 60.0];
j6 = [46.0, 60.0];
j7 = [62.0, 48.0];
j9 = [56.0, 6.0];
u1 = [17.0, 26.0];
de9_centres = [17.54, 51.54];
usb_y = 17.5;

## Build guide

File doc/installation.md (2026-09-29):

# installation

## configuration

the file [CMakeLists.txt](/CMakeLists.txt) has a small number of configuration options. the critical aspects of the build can be specified on the `cmake` commandline; you should not normally need to edit the [CMakeLists.txt](/CMakeLists.txt) file unless you are doing something outlandish.

## building the source code

prior to installation, ensure you have cmake, gnu make and gcc targetted to arm-none-eabi. you should be able to find these in debian. homebrew in macos has a cask for prebuilt gcc 10 binaries from arm. under windows, you're probably best off using wsl.

clone the repository. once cloned, you'll need to initialise the pico sdk and external dependency submodules.

```shell
$ git submodule update --init --recursive
```

tinyusb and the cyw43 driver are pinned separately in `lib/` so they can be updated independently of the pico sdk. to use another checkout, pass the corresponding path to cmake:

| dependency | cmake option |
| --- | --- |
| tinyusb | `-DPICO_TINYUSB_PATH=/path/to/tinyusb` |
| cyw43 driver | `-DPICO_CYW43_DRIVER_PATH=/path/to/cyw43-driver` |

when it's ready, start cmake off; you'll need to specify the board type you're using. if you omit it, you'll get a build for the default target, amigahid-pico standard pcb revision 4. this is akin to running:

```shell
$ cmake -B build/ -S . -DBOARD_TYPE=BOARD_HIDPICO_REV4
```

but you can also run this to get a revision 2 pcb build (the pin assignments are different):

```shell
$ cmake -B build/ -S . -DBOARD_TYPE=BOARD_HIDPICO_REV2
```

for a revision 5 pcb, select its dedicated target to enable the second controller port:

```shell
$ cmake -B build/ -S . -DBOARD_TYPE=BOARD_HIDPICO_REV5
```

supported targets are revision 2, revision 4 and revision 5. choose the revision
printed on the carrier PCB, separately from the Pico/Pico W module. REV5 defaults
to mouse on controller port 1 and joystick on controller port 2. REV4 has a
port-2 wiring error, so its firmware leaves that port unused; see the
[errata](errata.md#board-revision-4).

you can also enable generation of debug symbols so as to use `openocd` and `gdb` to debug a running target over serial-wire debug (swd). to do this, add the parameter `-DCMAKE_BUILD_TYPE=Debug`, e.g.:

```shell
$ cmake -B build/ -S . -DBOARD_TYPE=BOARD_HIDPICO_REV4 -DCMAKE_BUILD_TYPE=Debug
```

a 'Release' build is generated by default.

the oled footer shows `git describe --tags --always --long --abbrev=7`, for example
`0.1.1-21-gabc1234`: the nearest release tag, the number of commits since it, and the
current commit. this is refreshed on each build. a trailing `*` indicates changes to
tracked firmware, build or dependency files; unrelated pcb edits do not affect it.
checkouts without reachable tags show only the commit hash; source archives without
git metadata show `unknown`. the same version is printed in the uart startup banner.

on the `features` branch, hold F12 for one second to open the OLED settings menu.
see [runtime configuration](runtime-configuration.md) for settings, saving and
the F12+Esc recovery gesture.

for usb and bluetooth input on a pico w, enable the bluetooth host explicitly:

```shell
$ cmake -B build/ -S . -DPICO_BOARD=pico_w -DBOARD_TYPE=BOARD_HIDPICO_REV4 -DENABLE_BLUETOOTH_HID=ON
```

use `-DBOARD_TYPE=BOARD_HIDPICO_REV5` instead for a REV5 carrier. Bluetooth supports
keyboards and mice, Stadia LE gamepads, and a DualShock 4 Classic Bluetooth trial
with touchpad mouse input. See [joystick setup and validation status](joystick.md).

bluetooth builds apply the patches in `cmake/patches/` to dependency copies under the build directory. these retain btstack's report-to-boot protocol fallback and fix cyw43 debug format strings with the dependency versions selected here. the upstream submodule checkouts are left unchanged. alternate btstack or cyw43 checkouts must also accept these patches.

then build:

```shell
$ cd build && cmake --build build/
```

see next section for installing on a pico.

## installing on a pi pico (or similar) board

for the simplest option, pick usb. swd is good for remote debugging and reprogramming without detaching devices.

### usb (bootsel)

take a powered down pico, hold the bootsel button and attach a micro usb cable. copy the `amigahid-pico.uf2` file from `build/src/` to the mounted usb storage volume. the pico will spontaneously disconnect, and when it comes back, it will be running the amigahid-pico code. disconnect usb and attach an otg adapter.

### serial wire debug (swd)

swd uses openocd to program the flash memory attached to the rp2040.

to use swd to install the firmware, see chapter 5 of [getting started with raspberry pi pico](https://datasheets.raspberrypi.com/pico/getting-started-with-pico.pdf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).

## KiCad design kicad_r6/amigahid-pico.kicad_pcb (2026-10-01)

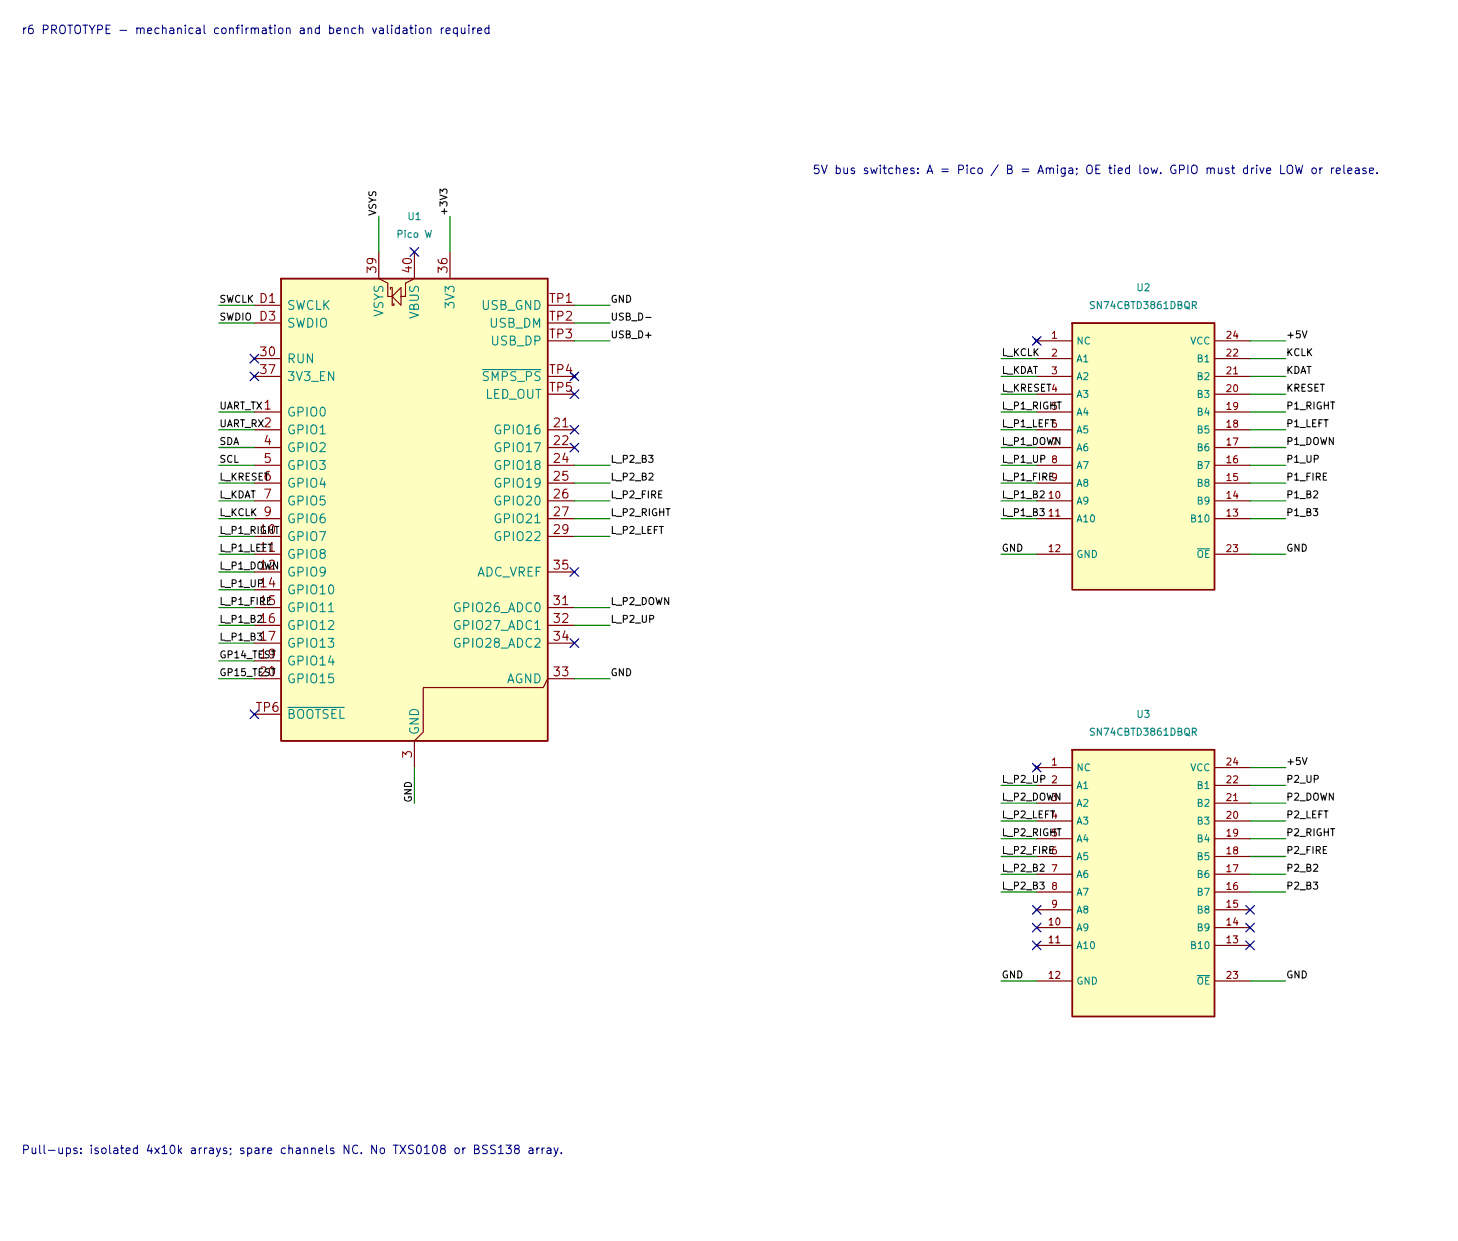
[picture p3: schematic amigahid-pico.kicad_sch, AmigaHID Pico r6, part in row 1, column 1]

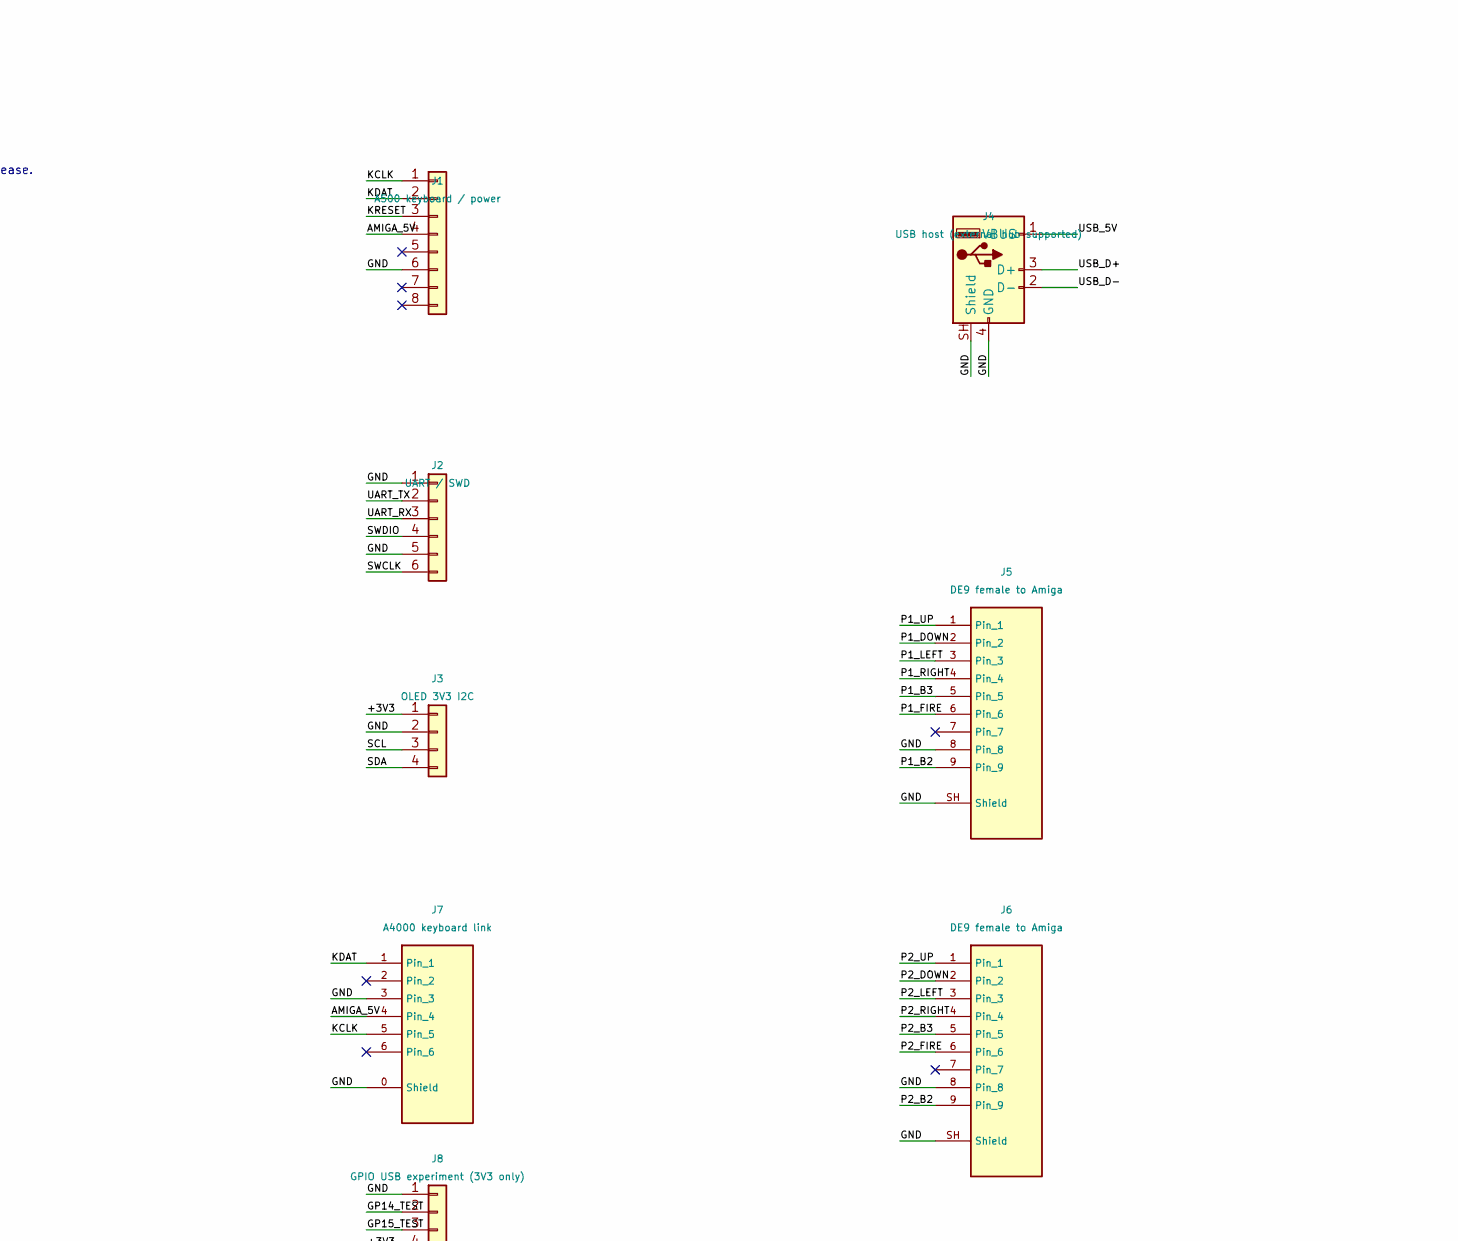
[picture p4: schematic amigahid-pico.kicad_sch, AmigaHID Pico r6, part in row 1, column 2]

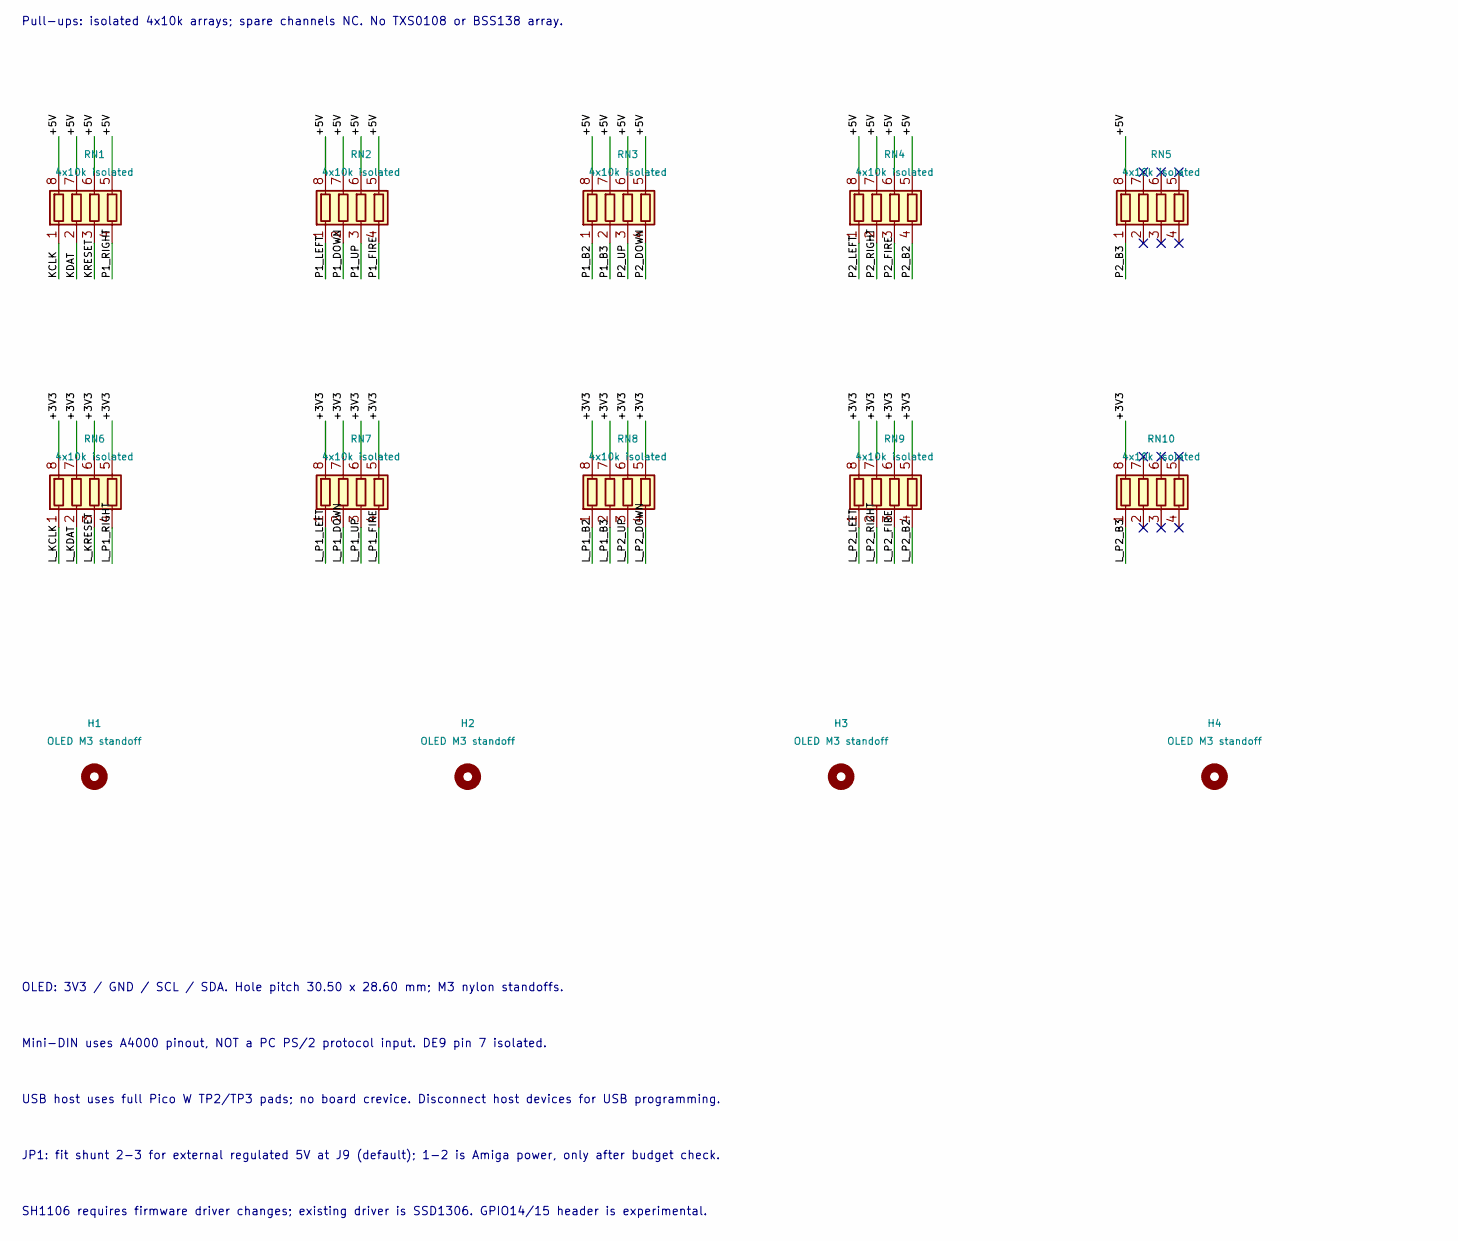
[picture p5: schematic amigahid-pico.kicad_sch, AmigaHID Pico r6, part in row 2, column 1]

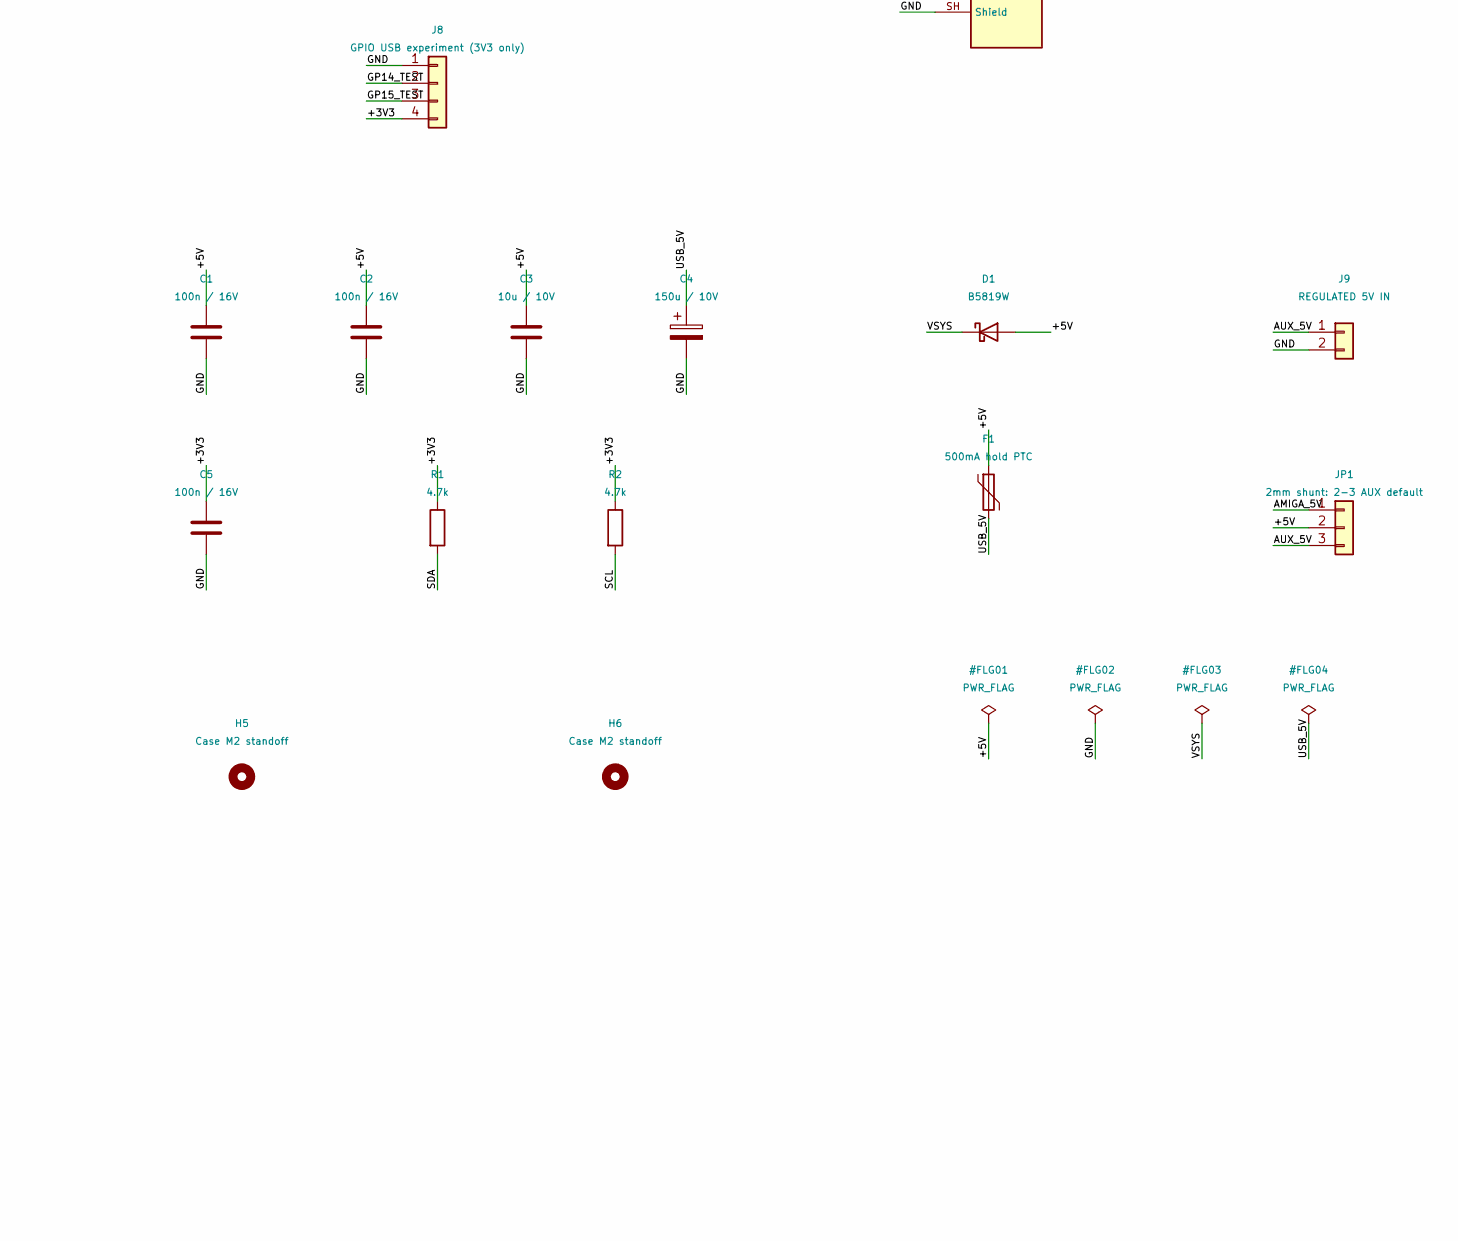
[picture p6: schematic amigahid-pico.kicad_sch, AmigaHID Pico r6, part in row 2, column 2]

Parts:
C1, C2, C5: 100n / 16V; C_0603_1608Metric; MPN CC0603KRX7R9BB104; LCSC Stock 8519800
C3: 10u / 10V; C_0805_2012Metric; MPN CL21A106KAYNNNE; LCSC Stock 594040
C4: 150u / 10V; CP_Elec_6.3x5.4; MPN RVT1A151M0605 150UF 10V; LCSC Stock 520
D1: B5819W; D_SOD-123; MPN B5819W SL; LCSC Stock 229920
F1: 500mA hold PTC; Fuse_1206_3216Metric; MPN MF-NSMF050-2; LCSC Stock 59460
H1, H2, H3, H4: OLED M3 standoff; MountingHole_3.2mm_M3
H5, H6: Case M2 standoff; MountingHole_2.2mm_M2
J1: A500 keyboard / power; PinHeader_1x08_P2.54mm_Vertical; MPN X6511WV-08H-C60D30; LCSC Stock 610
J2: UART / SWD; PinHeader_1x06_P2.54mm_Vertical; MPN X6511WV-06H-C60D30; LCSC Stock 400
J3: OLED 3V3 I2C; PinSocket_1x04_P2.54mm_Vertical; MPN DS1023-1x4SF11; LCSC Stock 2530
J4: USB host (external hub supported); USB_A_R6; MPN UBA-4R-D14-4D(LF)(SN); LCSC Stock 265
J5, J6: DE9 female to Amiga; DE9_Female_R6; MPN LCK-205A09FJ2A00B1A; LCSC Stock 1935
J7: A4000 keyboard link; MiniDIN6_R6; MPN DIN-603; LCSC Stock 225
J8: GPIO USB experiment (3V3 only); PinHeader_1x04_P2.54mm_Vertical; MPN X6511WV-04H-C60D30; LCSC Stock 26130
J9: REGULATED 5V IN; PinHeader_1x02_P2.54mm_Vertical; MPN X6511WV-02H-C60D30; LCSC Stock 17940
JP1: 2mm shunt: 2-3 AUX default; PinHeader_1x03_P2.00mm_Vertical; MPN PZ2.0-1x3PZZ-L8.7; LCSC Stock 3850
R1, R2: 4.7k; R_0603_1608Metric; MPN 0603WAF4701T5E; LCSC Stock 13626200
RN1, RN2, RN3, RN4, RN5, RN6, RN7, RN8, RN9, RN10: 4x10k isolated; R_Array_Convex_4x0603; MPN EXB38V103JV; LCSC Stock 53500
U1: Pico W; Pico_2_W_R6; MPN Raspberry Pi Pico W; LCSC Stock 855
U2, U3: SN74CBTD3861DBQR; SSOP-24_3.9x8.7mm_P0.635mm; MPN SN74CBTD3861DBQR; LCSC Stock 117

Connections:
/+3V3: C5.1, J3.1, J8.4, R1.1, R2.1, RN6.5 (R4.2), RN6.6 (R3.2), RN6.7 (R2.2), RN6.8 (R1.2), RN7.5 (R4.2), RN7.6 (R3.2), RN7.7 (R2.2), RN7.8 (R1.2), RN8.5 (R4.2), RN8.6 (R3.2), RN8.7 (R2.2), RN8.8 (R1.2), RN9.5 (R4.2), RN9.6 (R3.2), RN9.7 (R2.2), RN9.8 (R1.2), RN10.8 (R1.2), U1.36 (3V3)
/+5V: C1.1, C2.1, C3.1, D1.2 (A), F1.1, JP1.2, RN1.5 (R4.2), RN1.6 (R3.2), RN1.7 (R2.2), RN1.8 (R1.2), RN2.5 (R4.2), RN2.6 (R3.2), RN2.7 (R2.2), RN2.8 (R1.2), RN3.5 (R4.2), RN3.6 (R3.2), RN3.7 (R2.2), RN3.8 (R1.2), RN4.5 (R4.2), RN4.6 (R3.2), RN4.7 (R2.2), RN4.8 (R1.2), RN5.8 (R1.2), U2.24 (VCC), U3.24 (VCC)
/AMIGA_5V: J1.4, J7.4, JP1.1
/AUX_5V: J9.1, JP1.3
/GP14_TEST: J8.2, U1.19 (GPIO14)
/GP15_TEST: J8.3, U1.20 (GPIO15)
/KCLK: J1.1, J7.5, RN1.1 (R1.1), U2.22 (B1)
/KDAT: J1.2, J7.1, RN1.2 (R2.1), U2.21 (B2)
/KRESET: J1.3, RN1.3 (R3.1), U2.20 (B3)
/L_KCLK: RN6.1 (R1.1), U1.9 (GPIO6), U2.2 (A1)
/L_KDAT: RN6.2 (R2.1), U1.7 (GPIO5), U2.3 (A2)
/L_KRESET: RN6.3 (R3.1), U1.6 (GPIO4), U2.4 (A3)
/L_P1_B2: RN8.1 (R1.1), U1.16 (GPIO12), U2.10 (A9)
/L_P1_B3: RN8.2 (R2.1), U1.17 (GPIO13), U2.11 (A10)
/L_P1_DOWN: RN7.2 (R2.1), U1.12 (GPIO9), U2.7 (A6)
/L_P1_FIRE: RN7.4 (R4.1), U1.15 (GPIO11), U2.9 (A8)
/L_P1_LEFT: RN7.1 (R1.1), U1.11 (GPIO8), U2.6 (A5)
/L_P1_RIGHT: RN6.4 (R4.1), U1.10 (GPIO7), U2.5 (A4)
/L_P1_UP: RN7.3 (R3.1), U1.14 (GPIO10), U2.8 (A7)
/L_P2_B2: RN9.4 (R4.1), U1.25 (GPIO19), U3.7 (A6)
/L_P2_B3: RN10.1 (R1.1), U1.24 (GPIO18), U3.8 (A7)
/L_P2_DOWN: RN8.4 (R4.1), U1.31 (GPIO26_ADC0), U3.3 (A2)
/L_P2_FIRE: RN9.3 (R3.1), U1.26 (GPIO20), U3.6 (A5)
/L_P2_LEFT: RN9.1 (R1.1), U1.29 (GPIO22), U3.4 (A3)
/L_P2_RIGHT: RN9.2 (R2.1), U1.27 (GPIO21), U3.5 (A4)
/L_P2_UP: RN8.3 (R3.1), U1.32 (GPIO27_ADC1), U3.2 (A1)
/P1_B2: J5.9, RN3.1 (R1.1), U2.14 (B9)
/P1_B3: J5.5, RN3.2 (R2.1), U2.13 (B10)
/P1_DOWN: J5.2, RN2.2 (R2.1), U2.17 (B6)
/P1_FIRE: J5.6, RN2.4 (R4.1), U2.15 (B8)
/P1_LEFT: J5.3, RN2.1 (R1.1), U2.18 (B5)
/P1_RIGHT: J5.4, RN1.4 (R4.1), U2.19 (B4)
/P1_UP: J5.1, RN2.3 (R3.1), U2.16 (B7)
/P2_B2: J6.9, RN4.4 (R4.1), U3.17 (B6)
/P2_B3: J6.5, RN5.1 (R1.1), U3.16 (B7)
/P2_DOWN: J6.2, RN3.4 (R4.1), U3.21 (B2)
/P2_FIRE: J6.6, RN4.3 (R3.1), U3.18 (B5)
/P2_LEFT: J6.3, RN4.1 (R1.1), U3.20 (B3)
/P2_RIGHT: J6.4, RN4.2 (R2.1), U3.19 (B4)
/P2_UP: J6.1, RN3.3 (R3.1), U3.22 (B1)
/SCL: J3.3, R2.2, U1.5 (GPIO3)
/SDA: J3.4, R1.2, U1.4 (GPIO2)
/SWCLK: J2.6, U1.D1 (SWCLK)
/SWDIO: J2.4, U1.D3 (SWDIO)
/UART_RX: J2.3, U1.2 (GPIO1)
/UART_TX: J2.2, U1.1 (GPIO0)
/USB_5V: C4.1, F1.2, J4.1 (VBUS)
/USB_D+: J4.3 (D+), U1.TP3 (USB_DP)
/USB_D-: J4.2 (D-), U1.TP2 (USB_DM)
/VSYS: D1.1 (K), U1.39 (VSYS)
GND: C1.2, C2.2, C3.2, C4.2, C5.2, J1.6, J2.1, J2.5, J3.2, J4.4 (GND), J4.SH (Shield), J5.8, J5.SH (Shield), J6.8, J6.SH (Shield), J7.0 (Shield), J7.3, J8.1, J9.2, U1.3 (GND), U1.8 (GND), U1.13 (GND), U1.18 (GND), U1.23 (GND), U1.28 (GND), U1.33 (AGND), U1.38 (GND), U1.D2 (GND), U1.TP1 (USB_GND), U2.12 (GND), U2.23 (~OE), U3.12 (GND), U3.23 (~OE)

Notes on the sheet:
r6 PROTOTYPE - mechanical confirmation and bench validation required
5V bus switches: A = Pico / B = Amiga; OE tied low. GPIO must drive LOW or release.
Pull-ups: isolated 4x10k arrays; spare channels NC. No TXS0108 or BSS138 array.
OLED: 3V3 / GND / SCL / SDA. Hole pitch 30.50 x 28.60 mm; M3 nylon standoffs.
Mini-DIN uses A4000 pinout, NOT a PC PS/2 protocol input. DE9 pin 7 isolated.
USB host uses full Pico W TP2/TP3 pads; no board crevice. Disconnect host devices for USB programming.
JP1: fit shunt 2-3 for external regulated 5V at J9 (default); 1-2 is Amiga power, only after budget check.
SH1106 requires firmware driver changes; existing driver is SSD1306. GPIO14/15 header is experimental.

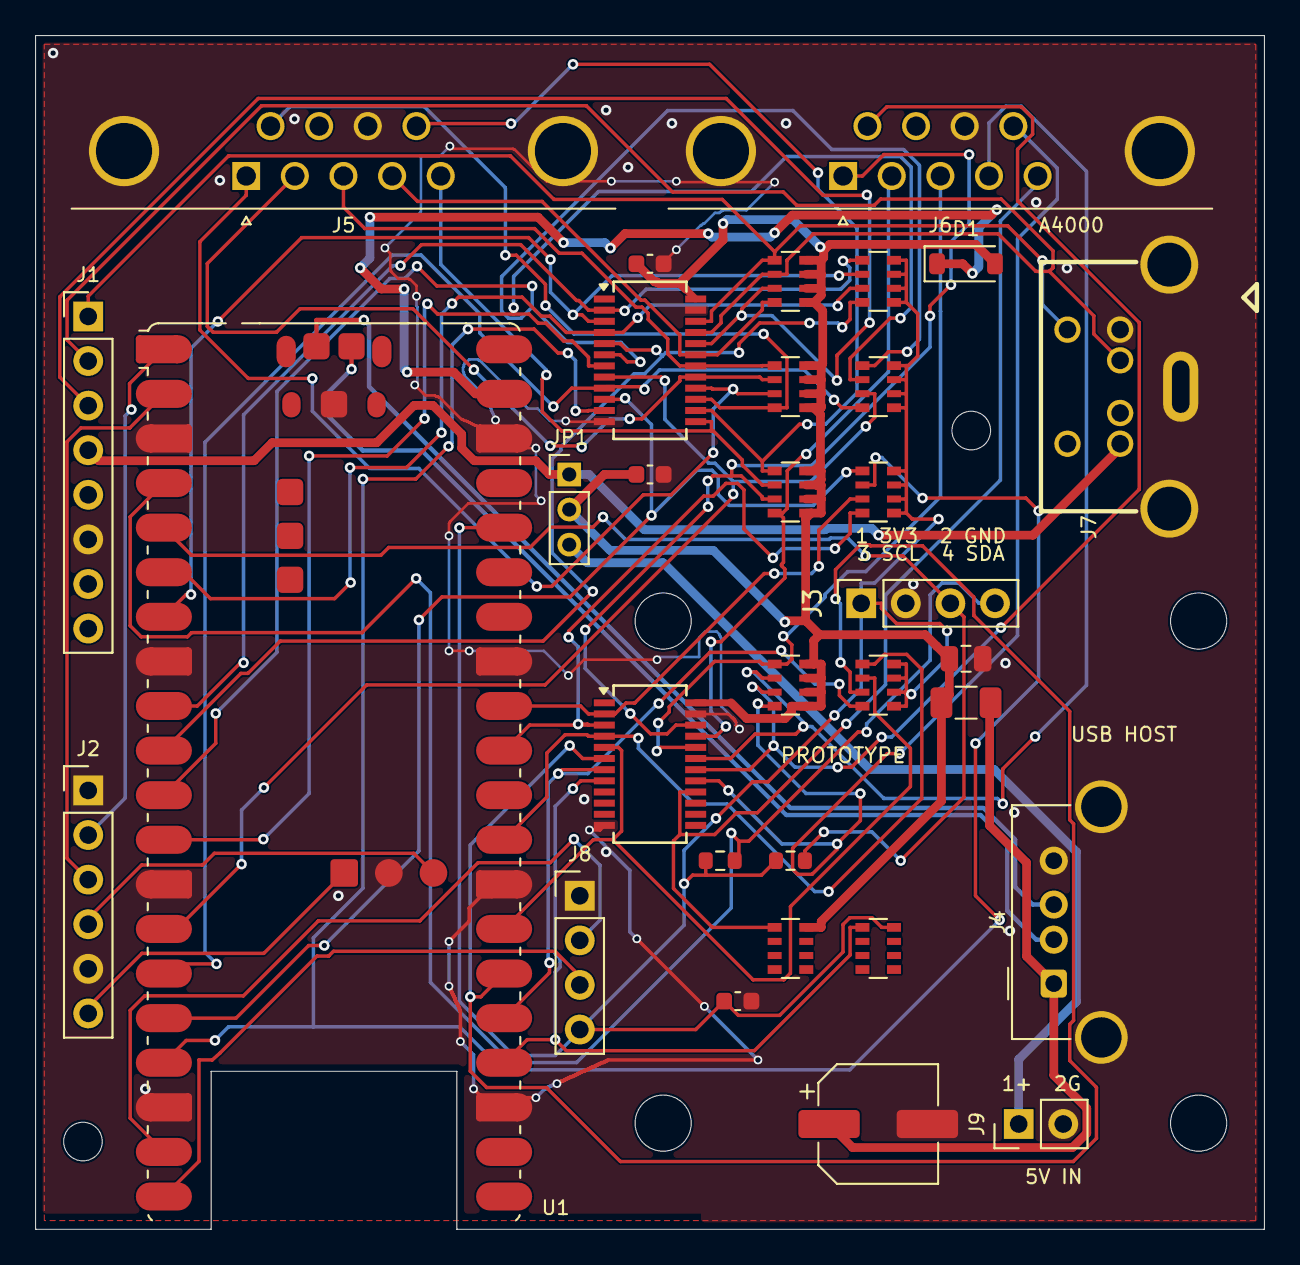
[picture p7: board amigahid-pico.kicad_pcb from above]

Board: 2 copper layers, 70.0 x 68.0 mm, 38 parts (0 on the bottom side), 51 nets.

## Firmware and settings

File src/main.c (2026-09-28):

/**
 * this file is part of amigahid-pico, (c) 2021 just nine <nine@aphlor.org>
 * please locate the full source at https://github.com/borb/amigahid-pico
 *
 * released under the terms of the Eclipse Public License 2.0 (EPL-2.0).
 * please find the complete license text at https://spdx.org/licenses/EPL-2.0
 *
 * main entry point for amigahid-pico.
 */

// these reside within the tinyusb sdk and are not part of this project source
#include "bsp/board.h"
#include "tusb.h"

#include "display/disp_ssd.h"
#include "platform/amiga/keyboard_serial_io.h"
#include "platform/amiga/quad_mouse.h"
#include "util/debug_cons.h"
#include "util/output.h"

#include "config.h"
#include "tusb_config.h"
#include "settings.h"
#include "runtime_menu.h"
#include "usb_hid.h"

#ifdef ENABLE_BLUETOOTH_HID
#include "bt_hid.h"
#endif

// main entry point
int main(void)
{
    // tinyusb board init; led, uart, button, usb
    board_init();
    settings_init();

    // initialise the i2c controller and send the init sequence to the display
    disp_ssd_init();

    // say hello, trevor ("hello, trevor")
    dbgcons_init();

    // initialise the usb host stack on the rhport from tusb_config.h
    const tusb_rhport_init_t rhport_init = {
        .role = TUSB_ROLE_HOST,
        .speed = TUH_OPT_HIGH_SPEED ? TUSB_SPEED_HIGH : TUSB_SPEED_FULL,
    };
    tusb_init(BOARD_TUH_RHPORT, &rhport_init);

    // we're single arch right now, but in future this should hand off to whatever the
    // configured arch is
    amiga_init();

    // start amiga mouse emulation
    amiga_quad_mouse_init();

#ifdef ENABLE_BLUETOOTH_HID
    bt_hid_init();
#endif
    runtime_menu_init();

    while (1) {
        // run host mode jobs (hotplug events, packet io callbacks)
        tuh_task();
        hid_app_task();

#ifdef ENABLE_BLUETOOTH_HID
        bt_hid_task();
#endif

        // amiga keyboard service routine
        amiga_service();
        runtime_menu_task();

        // Render deferred Bluetooth status and reclaim completed OLED DMA buffers.
        dbgcons_task();
        disp_ssd_task();
        runtime_menu_watchdog_task();
    }

    return 0;
}

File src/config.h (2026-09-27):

/**
 * this file is part of amigahid-pico, (c) 2021 just nine <nine@aphlor.org>
 * please locate the full source at https://github.com/borb/amigahid-pico
 *
 * released under the terms of the Eclipse Public License 2.0 (EPL-2.0).
 * please find the complete license text at https://spdx.org/licenses/EPL-2.0
 *
 * hid-pico configuration
 *
 * PLEASE NOTE ALL PIN DESIGNATIONS ARE GPIO PIN NUMBERS - NOT PHYSICAL PIN NUMBERS
 */

#ifndef _CONFIG_H
#define _CONFIG_H

// the pico has an onboard led on gp25; use this as a default indicator
#ifndef INDICATOR_LED
#  define INDICATOR_LED PICO_DEFAULT_LED_PIN
#endif

#if defined(BOARD_HIDPICO_REV2)
#  define HAS_SCREEN
#  define HAS_KEYBOARD
#  define HAS_PORT1
#  define HAS_PORT2

#  define I2C_PORT      i2c0
#  define I2C_PIN_SDA   4
#  define I2C_PIN_SCL   5
#  define I2C_IRQN      23

#  define KBD_AMIGA_RST 10
#  define KBD_AMIGA_DAT 11
#  define KBD_AMIGA_CLK 12

#  define QM1_AMIGA_HQ  7
#  define QM1_AMIGA_VQ  6
#  define QM1_AMIGA_H   9
#  define QM1_AMIGA_V   8
#  define QM1_AMIGA_B1  22
#  define QM1_AMIGA_B2  26
#  define QM1_AMIGA_B3  27
#elif defined(BOARD_HIDPICO_REV4) || defined(BOARD_HIDPICO_REV5)
#  define HAS_SCREEN
#  define HAS_KEYBOARD
#  define HAS_PORT1
#  define HAS_PORT2

#  define I2C_PORT      i2c1
#  define I2C_PIN_SDA   2
#  define I2C_PIN_SCL   3
#  define I2C_IRQN      24 // this is tied to the i2c port being used so get the right one!

#  define KBD_AMIGA_RST 4
#  define KBD_AMIGA_DAT 5
#  define KBD_AMIGA_CLK 6

#  define QM1_AMIGA_HQ  7
#  define QM1_AMIGA_VQ  8
#  define QM1_AMIGA_H   9
#  define QM1_AMIGA_V   10
#  define QM1_AMIGA_B1  11
#  define QM1_AMIGA_B2  12
#  define QM1_AMIGA_B3  13

#  if defined(BOARD_HIDPICO_REV5)
// REV5 fixes port 2's Down connection to RUN on REV4. Never enable this
// mapping for an unmodified REV4 board; RUN is not a programmable GPIO.
#    define HAS_JOYSTICK_PORT2
#    define QM2_AMIGA_HQ 21
#    define QM2_AMIGA_VQ 22
#    define QM2_AMIGA_H  26
#    define QM2_AMIGA_V  27
#    define QM2_AMIGA_B1 20
#    define QM2_AMIGA_B2 19
#    define QM2_AMIGA_B3 18
#  endif
#else
#  error Board type has not been defined; check cmake command line
#endif

#endif // _CONFIG_H

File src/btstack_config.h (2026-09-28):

#ifndef _PICO_BTSTACK_BTSTACK_CONFIG_H
#define _PICO_BTSTACK_BTSTACK_CONFIG_H

#ifndef ENABLE_BLE
#define ENABLE_BLE
#endif

#ifndef ENABLE_CLASSIC
#define ENABLE_CLASSIC
#endif

#ifndef ENABLE_LE_PERIPHERAL
#define ENABLE_LE_PERIPHERAL
#endif

#ifndef ENABLE_PRINTF_HEXDUMP
#define ENABLE_PRINTF_HEXDUMP
#endif
#define ENABLE_LE_CENTRAL
#define ENABLE_LOG_ERROR
#define ENABLE_LOG_INFO

#define HCI_OUTGOING_PRE_BUFFER_SIZE 4
#define HCI_ACL_PAYLOAD_SIZE (1691 + 4)
#define HCI_ACL_CHUNK_SIZE_ALIGNMENT 4

#define MAX_NR_AVDTP_CONNECTIONS 1
#define MAX_NR_AVDTP_STREAM_ENDPOINTS 1
#define MAX_NR_AVRCP_CONNECTIONS 1
#define MAX_NR_BNEP_CHANNELS 1
#define MAX_NR_BNEP_SERVICES 1
#define MAX_NR_BTSTACK_LINK_KEY_DB_MEMORY_ENTRIES 4
#define MAX_NR_GATT_CLIENTS 1
#define MAX_NR_HCI_CONNECTIONS 4
#define MAX_NR_HID_HOST_CONNECTIONS 2
#define MAX_NR_HIDS_HOSTS 1
#define MAX_NR_HFP_CONNECTIONS 1
#define MAX_NR_L2CAP_CHANNELS 6
#define MAX_NR_L2CAP_SERVICES 4
#define MAX_NR_RFCOMM_CHANNELS 1
#define MAX_NR_RFCOMM_MULTIPLEXERS 1
#define MAX_NR_RFCOMM_SERVICES 1
#define MAX_NR_SERVICE_RECORD_ITEMS 4
#define MAX_NR_SM_LOOKUP_ENTRIES 3
#define MAX_NR_WHITELIST_ENTRIES 1

#define MAX_NR_LE_DEVICE_DB_ENTRIES 4

#define MAX_NR_CONTROLLER_ACL_BUFFERS 3
#define MAX_NR_CONTROLLER_SCO_PACKETS 3

#define ENABLE_HCI_CONTROLLER_TO_HOST_FLOW_CONTROL
#define HCI_HOST_ACL_PACKET_LEN 1024
#define HCI_HOST_ACL_PACKET_NUM 3
#define HCI_HOST_SCO_PACKET_LEN 120
#define HCI_HOST_SCO_PACKET_NUM 3

#define NVM_NUM_DEVICE_DB_ENTRIES 16
#define NVM_NUM_LINK_KEYS 16

#define MAX_ATT_DB_SIZE 512

#define HAVE_EMBEDDED_TIME_MS
#define HAVE_ASSERT

#define HCI_RESET_RESEND_TIMEOUT_MS 1000

#define ENABLE_SOFTWARE_AES128
#define ENABLE_MICRO_ECC_FOR_LE_SECURE_CONNECTIONS
#define ENABLE_L2CAP_ENHANCED_RETRANSMISSION_MODE

#endif // _PICO_BTSTACK_BTSTACK_CONFIG_H

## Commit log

2026-09-27 config: add persistent settings and OLED menu
    Add a versioned settings record with CRC validation, alternating flash
    sectors, and linker protection for settings and Bluetooth storage.
    Register core1 for flash lockout in USB-only builds as well.
    Provide a keyboard-operated OLED menu with save, cancel, factory
    defaults, and a fixed boot recovery gesture. Route menu input locally
    and release held input before returning to the Amiga. Add runtime mouse
    timing, wheel direction, Right GUI behavior, display modes, and an
    optional main-loop watchdog.
    Track the existing plan and document completed work, remaining phases,
    controls, and hardware validation requirements. Temporary native checks
    cover i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
    [debug_cons.h, disp_ssd.c, main.c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]
2026-09-27 config: add persistent settings and OLED menu
    Document menu controls, settings persistence and recovery so users can
    configure the adapter without rebuilding firmware.
    Temporary native checks cov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
2026-09-27 input: add USB gamepad joystick emulation
    Decode HID hat switches, D-pad usages, absolute X/Y fields and Button 1
    into digital joystick output on the existing Amiga controller port.
    Support digital sticks such as the Competition Pro that encode switches
    in axis fields. Add a persistent port mode with schema-1 settings
    migration, and release controls across menu capture, mode changes and
    disconnects.
2026-09-27 amiga: enable joystick output on REV5 port 2
    Add the REV5 pin mapping and default to mouse on port 1 with a USB
    joystick on port 2. Keep both outputs active together, expose a separate
    port 2 setting, and migrate existing settings without losing saved
    preferences. Keep REV2 and REV4 builds limited to port 1.
2026-09-28 debug: show USB joystick reports and routed controls
    Expose received packet count and length, decode status, receive-request
    status, and the combined joystick state in HID diagnostics. Show when
    menu capture is waiting for neutral input, rate-limit OLED updates, and
    preserve Bluetooth pairing messages.
    Keep report decoding and GPIO behavior unchanged while investigating the
    Competition Pro's missing Amiga input. Document the diagnostic fields
    and current hardware findings.
2026-09-28 usb: initialize PS3-compatible joystick input
    Send the asynchronous PS3 enable-report command only for USB ID
    054c:0268 with the expected 49-byte report ID 1 layout. Map its D-pad
    and face buttons to digital directions and fire, and show USB identity
    and startup status while waiting for the first report.
    The Competition Pro exposes a 49-byte layout on the Pico and sends no
    reports, unlike its 9-byte Linux layout. This adds the missing PS3
    startup path; confirmation of the controller identity and behavior on
    hardware remains pending. Native checks cover matching, queue retry,
    completion and failure, reconnect, controls, and generic HID
    regressions.
    [main.c]
2026-09-28 bluetooth: add LE HID gamepad input
    Discover HID report maps and subscribe to input reports for LE gamepads
    without boot keyboard or mouse reports. Use active scanning, route
    decoded controls through the existing joystick bridge, and retain final
    gamepad state across queue overflow and disconnects.
    Add OLED gamepad diagnostics and rename the controller menu mode to
    Joystick while preserving saved settings. Native checks cover the
    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
2026-09-28 bluetooth: add LE HID gamepad input
    published Stadia descriptor, event handling, queue recovery, existing
    boot-device paths and diagnostics; Stadia pairing and gameplay still
    need hardware validation.
    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
2026-09-29 docs: record Stadia gamepad hardware validation
    Record successful pairing and D-pad/A-button input in Amiga Test Kit on
    Pico W/REV5 with de9ae63. Keep left-stick thresholds,
    disconnect/reconnect and extended play listed as pending hardware
    checks.
2026-09-29 input: preserve mouse button holds across devices
    Combine per-source mouse button states so a release or disconnect cannot
    release a button still held by another device. Resynchronize the
    aggregate when capturing input or changing controller modes.
2026-09-29 input: map additional gamepad buttons to Amiga controls
    Drive all three Amiga joystick button lines. Map PS4 Cross/Circle/Square
    and Stadia A/B/X to buttons 1/2/3, using HID Button 4 when Button 3 is
    absent. Preserve the Competition Pro PS3-mode fire mapping.
    Map PS4 L1 and touchpad click to left mouse, R1 to right, and either
    trigger to middle. Record successful REV5 hardware validation for both
    controllers.
2026-09-29 input: map additional gamepad buttons to Amiga controls
    trigger to middle. Document the button assignments so users can
    distinguish mouse clicks from joystick actions.
    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
2026-09-30 input: add saved gamepad mappings and stick settings
    Make direction sources, deadzone, seven output button mappings, and PS4
    mouse controls configurable. Preserve controller defaults and carry
    seven buttons through USB, Bluetooth, and the input bridge for CD32
    output.
2026-09-30 keyboard: add saved presets and custom key mappings
    Add Help/Delete and ISO-key choices, letter-layout presets, and eight
    learned-source remap slots. Aggregate translated keys across input
    sources so aliases and shared modifiers remain held until every source
    releases them.
2026-09-30 amiga: add PIO-backed CD32 pad emulation
    Add explicit CD32 port modes with seven-button snapshots, identification
    bits, and open-drain fire/clock handover. Keep mouse and CD32 output
    simultaneous on REV5 and reserve PIO1 so the wireless driver can use
    PIO0.
    Migrate controller modes in settings schema 7, publish settings
    atomically, and discard stale Bluetooth input during radio transitions.
    Document the combined trial and native protocol, migration, mapping, and
    reset validation; hardware testing remains pending.
    [cd32.c, quad_mouse.c]
2026-09-30 amiga: add PIO-backed CD32 pad emulation
    Document CD32 setup, button mappings and shared-port constraints.
    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
2026-10-01 hardware: add r6 Pico W adapter and sourced components
    Add the routed carrier, project libraries, sourcing metadata and
    validation tools. Include direct Amiga connectors, OLED and case
    mounts, and antenna cutout.
    Exclude generated fabrication files, local KiCad state and r5
    reference material.
    [SOURCING.csv, amigahid-pico.kicad_pcb, amigahid-pico.kicad_sch]
2026-10-01 case: add YAPP enclosure for the r6 adapter
    Add connector and OLED cutouts, PCB mounts, and blind snap pockets.
    Keep the optional auxiliary power opening disabled by default.
    Include the pinned YAPP dependency, PCB geometry input, and build
    and mesh validation tools. Exclude generated models, previews, and
    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
    [amigahid-pico-case.scad, pcb-mechanics.scad]
2026-10-15 hid: Separate DS4 mouse buttons from CD32 triggers
    Map L2 and R2 to CD32 Rewind and Forward in the default gamepad
    mapping. Keep touchpad click as the left mouse button and use L1
    and R1 for middle and right clicks so the controls do not overlap.
    Update the joystick guide to match the mouse and CD32 assignments.
2026-10-15 amiga: Drive CD32 serial data high between active bits
    Drive the data pin high and low during serial reads so weak pull-ups
    need not charge the Amiga POT input capacitance between bits. Invert
    the pressed-button snapshot to produce active-low serial levels.
    Restore the open-drain latch when select returns high. Keep normal
    joystick buttons and the shared fire/clock line open-drain.
    Document serial output ownership and the updated PIO resource use.
    The electrical change still needs confirmation on Amiga hardware.
2026-10-15 prefs: Add an opt-in Amiga preferences link on port 2
    Add a fixed-size CRC-protected protocol shared with the Amiga client.
    Use core1 to exchange frames over the second controller port and core0
    to validate settings, apply changes and save alternating flash records.
    Cache replies to avoid repeating writes when requests are retried.
    Expose the link through the runtime menu and allow F12 cancellation.
    Suspend port 2 output while connected, discard stale generations and
    wait for neutral controls before restoring joystick or CD32 output.
    Keep port 1 and keyboard input available during preferences sessions.
    Build the shared protocol with the firmware and include common sources
    in firmware versi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
2026-10-16 display: Add selectable SH1106 OLED support
    Select SSD1306 or SH1106 through the DISPLAY_CONTROLLER CMake option,
    keeping SSD1306 as the default with its existing initialization and
    transfer behavior.
    For SH1106, enable the DC/DC converter and send each framebuffer page
    with its own address and two-column offset at 400 kHz. Reserve queue
    capacity for eight pages before submitting an update. Reuse the
    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
2026-11-07 case: Add the r7 enclosure and shared OLED mounts
    Add the YAPP enclosure for the r7 board with shared PCB and OLED mounts,
    connector openings, a recessed recovery access hole and Amiga-style
    ribs. Include PCB geometry extraction, mesh validation and build scripts
    with the vendored generator and OLED reference drawings.
    Keep generated meshes and previews local. The modeled clearances still
    require validation with an assembled board and printed enclosure.
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2026-11-07 case: Add Amiga-styled r6.2 enclosure
    Preserve the r6 PCB mechanics with a recessed rib band, sloped lid
    shoulder and beveled OLED window. Include the patched YAPP generator,
    geometry inputs and build tools while excluding generated outputs.
    Correct the revision labels and keep PCB extraction output in r6.2.
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2026-11-07 docs: Focus device guides on current behavior and usage
    Describe setup, controls, troubleshooting and compatibility without
    trial chronology, old build identifiers or temporary test reports.
    Keep hardware validation limits and explain settings persistence and
    the Amiga-side preferences workflow.
    Match diagnostic examples to the three-digit control masks printed by
    the firmware and clarify that the watchdog message reports a reset.
2026-11-10 kicad_r7: Hold RUN low until the flash supply is ready
    Add a TPS3808G33 supervisor with local bypassing and a delayed RUN
    release. Separate the recovery request from RUN so automatic resets
    cannot preset the BOOTSEL latch; retain button-driven ROM recovery.
    Update the routed board, schematic, sourcing fields and assembly data.
    Add pin/net checks and document the required power-ramp validation.
    Keep the factory export part count derived from the circuit data.
    The reset-only board passes ERC, DRC and schematic parity checks.
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2026-11-10 case_r7: Accommodate the ALPS lever on the USB-C edge
    Extract SW2 placement from the board to align the lever slot and PCB
    support. Add recessed finger access, move the adjacent snap and keep
    the lever clear of the top and mouse-port wall.
    Include the estimated rocking and push envelope in collision checks
    and provide an assembled menu-edge preview. Document the switch
    position, optional closed wall and physical-fit checks.
    Both printable halves pass manifold checks and the modeled hardware
    intersection is empty. Confirm travel and finger access with a sample.
2026-11-10 case_r7: Increase snap engagement by 0.10 mm
    Reduce radial tab-to-recess clearance from 0.15 mm to 0.05 mm so the
    case halves hold together more firmly. Expose the clearance parameter
    for printer and material tuning while retaining the blind pockets.
    Rebuilt base and lid meshes are closed and the modeled hardware
    intersection remains empty. Snap force still needs a printed pair.
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
